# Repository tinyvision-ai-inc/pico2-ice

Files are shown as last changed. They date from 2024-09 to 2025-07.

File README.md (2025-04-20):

# pico2-ice

[Doc](http://pico2-ice.tinyvision.ai/)
| [Hardware](https://github.com/tinyvision-ai-inc/pico2-ice)
| [SDK](https://github.com/tinyvision-ai-inc/pico-ice-sdk)
| [Schematic](https://raw.githubusercontent.com/tinyvision-ai-inc/pico2-ice/docs/Board/Rev1/pico2-ice.pdf)
| [Assembly](https://htmlpreview.github.io/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)
| [Discord](https://discord.gg/t2CzbAYeD2)

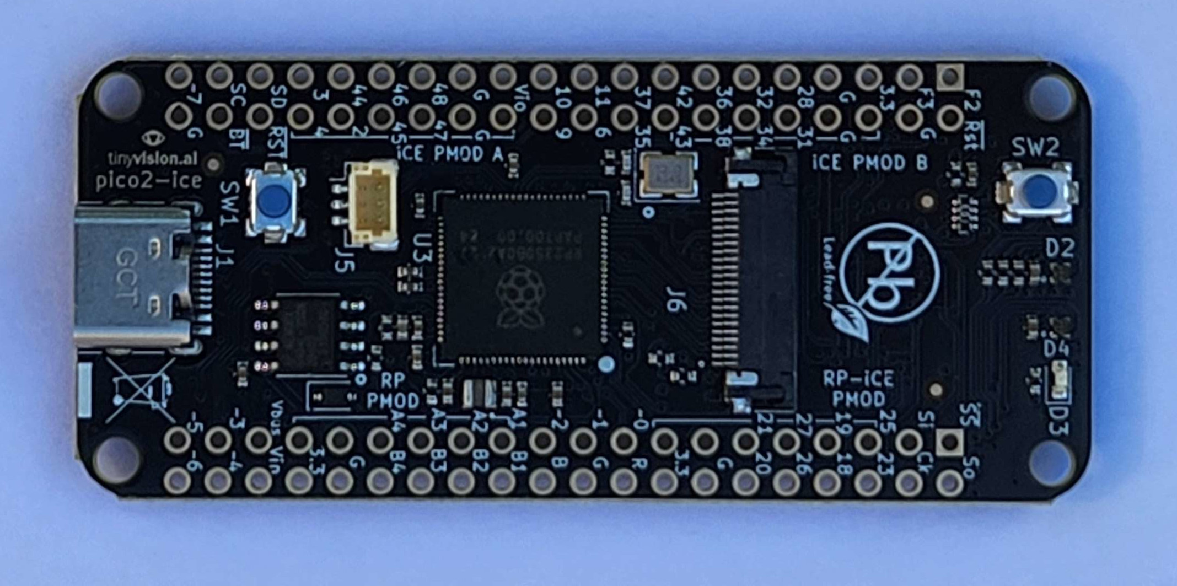
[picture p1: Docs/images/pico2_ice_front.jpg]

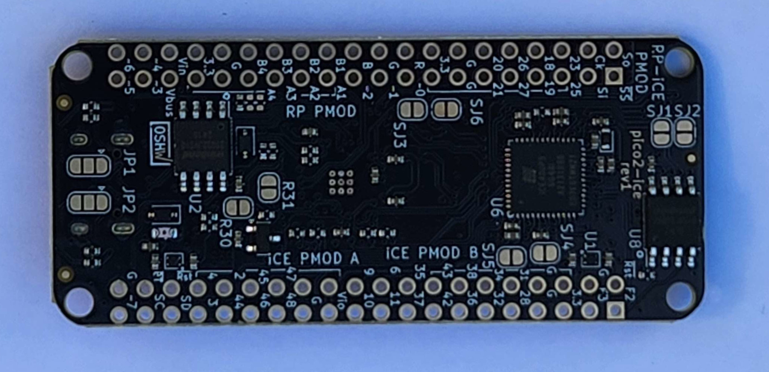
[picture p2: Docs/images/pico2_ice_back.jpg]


## PCB Design Files, Designs, Documentation

The pico2-ice is a small, low cost board with the Raspberry Pi Pico processor ([RP2350](https://www.raspberrypi.com/documentation/microcontrollers/silicon.html#rp2350)) and a Lattice Semiconductor [iCE40UP5K](https://www.latticesemi.com/en/Products/FPGAandCPLD/iCE40UltraPlus) FPGA. The board features independent flash for the FPGA and RP2350, low power PSRAM, a couple of pushbuttons and a two 3 color LED with _all_ FPGA and RP2350 pins brought out to easy to use 0.1" header pins (arranged as Pmod's) for fast prototyping.

The tinyVision.ai pico2-ice board Features:

* Raspberry Pi RP2350B processor
* Lattice UltraPlus ICE40UP5K FPGA with 5.3k LUTs, 1Mb SPRAM, 120Kb DPRAM, 8 Multipliers
* _ALL_ RP2350 and 32 FPGA GPIO on 0.1” headers
* 4MB SPI Flash
* 8MB low power qSPI SRAM
* 2 RGB LED, one for the RP2350 and one for the FPGA
* 2 pushbuttons, 1 for RP2350 boot mode that can also be used for other functions, and one for the FPGA
* On board 3.3V and 1.2V Regulators, can supply 3.3V to your project
* Open source schematic and layout using KiCAD design tools
* 4 layer board with a solid ground plane for good signal integrity

Firmware features:

* FPGA clock supplied by the RP2350, easy to program FPGA clock under SW control
* RP2350 can program the FPGA in various ways
* Micropython Firmware or C SDK

[OSHW US002732](https://certification.oshwa.org/us002732.html) | Certified open source hardware | oshwa.org/cert

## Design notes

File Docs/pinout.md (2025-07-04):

# Pinout Diagram

This diagram shows the ICE40 and RP2350 names for the through holes on the pico2-ice board. 

pinout diagram

[SVG](pinout.svg)
| [RP2350B](https://www.raspberrypi.com/documentation/pico-sdk/hardware.html#autotoc_md0)
| [ICE40](https://www.latticesemi.com/view_document?document_id=51971)

## With RTL on the iCE40

To program the FPGA, one needs to tell the synthesis tools which pins to connect to the signals in your RTL.  There are two different ways to name the pins.   The wafer names are words like `IOB_6a` and `IOT_8b`, and the pin numbers have names like `ICE_2`, `ICE_3`, and `ICE_4`.
Both sets of names can be found in this [PCF file](https://github.com/tinyvision-ai-inc/pico-ice-sdk/blob/main/rtl/pico_ice.pcf).

## With code on the RP2350

The FPGA pins and other signals are defined in [`pico_ice.h`](https://github.com/tinyvision-ai-inc/pico-ice-sdk/blob/pico2-ice_develop/include/boards/pico2_ice.h).

The PMOD pins can also be accessed from
[`ice_pmod.h`](https://github.com/tinyvision-ai-inc/pico-ice-sdk/blob/pico2-ice_develop/include/ice_pmod.h).

## SPI Pinouts 

For debugging the FPGA <-> SPI <-> Flash/RAM interface it is very helpful to use the 4 through holes on the upper right of the FPGA, and to connect a logic analyzer to the upper right PMOD.
Remember that the default boot process leaves the Flash switched ``off``.
With the Yosys icepack command, the ``-s`` option boots the Flash in the ``on`` state.

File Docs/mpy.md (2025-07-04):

# MicroPython

Pico-ice and pico2-ice support [MicroPython](https://micropython.org/).

## To install

- Acquire the [latest release](https://github.com/tinyvision-ai-inc/pico-ice-micropython/releases/latest) for the device you have.
- Program this `.uf2` file into the RP2350 as documented [here](programming_the_mcu.md).

## To use

The API to use the FPGA is as follow:

- `ice` is the microypthon module: `import ice`
- `ice.fpga` is the class provided by the module to manage the ICE40 FPGA: `ice.fpga(...)`
- `ice.fpga` provides the methods `stop()`, `start()`, and `cram(file)`

## How to program a bitstream to the FPGA RAM

- The `Pin` class is imported from the machine module to provide interfacing with the hardware.
- The module is imported
- The fpga type is configured with the approriate pins for the device, as well as the frequency (in MHz) that the FPGA will run at.
- The bitstream file is opened, in byte (as opposed to text) mode (`b`), to read (`r`).
- The fpga is brought out of reset with `fpga.start()`
- The bitstream is loaded into the FPGA using `fpga.cram(file)` with the previously opened file as argument.

### On pico-ice:

Make sure to adjust `frequency=` to the same frequency used by your FPGA design.
Often a lower value such as 12 MHz.

```python
from machine import Pin
import ice
fpga = ice.fpga(cdone=Pin(26), clock=Pin(24), creset=Pin(27), cram_cs=Pin(9), cram_mosi=Pin(8), cram_sck=Pin(10), frequency=48)
file = open("bitstream.bin", "br")
fpga.start()
fpga.cram(file)
```

### On pico2-ice:

Make sure to adjust `frequency=` to the same frequency used by your FPGA design.
Often a lower value such as 12 MHz.

```python
from machine import Pin
import ice
fpga = ice.fpga(cdone=Pin(40), clock=Pin(21), creset=Pin(31), cram_cs=Pin(5), cram_mosi=Pin(4), cram_sck=Pin(6), frequency=48)
file = open("bitstream.bin", "br")
fpga.start()
fpga.cram(file)
```

## How to program a bistream to the FPGA Flash (persistent bitstream)

### On pico-ice:

Make sure to adjust `frequency=` to the same frequency used by your FPGA design.
Often a lower value such as 12 MHz.

```python
from machine import Pin
import ice
file = open("bitstream.bin", "br")
flash = ice.flash(miso=Pin(8), mosi=Pin(11), sck=Pin(10), cs=Pin(9))
flash.erase(4096) # Optional
flash.write(file)
# Optional
fpga = ice.fpga(cdone=Pin(26), clock=Pin(24), creset=Pin(27), cram_cs=Pin(9), cram_mosi=Pin(8), cram_sck=Pin(10), frequency=48)
fpga.start()
```

### On pico2-ice:

Make sure to adjust `frequency=` to the same frequency used by your FPGA design.
Often a lower value such as 12 MHz.

```python
from machine import Pin
import ice
file = open("bitstream.bin", "br")
flash = ice.flash(miso=Pin(4), mosi=Pin(7), sck=Pin(6), cs=Pin(5))
flash.erase(4096) # Optional
flash.write(file)
# Optional
fpga = ice.fpga(cdone=Pin(40), clock=Pin(21), creset=Pin(31), cram_cs=Pin(5), cram_mosi=Pin(4), cram_sck=Pin(6), frequency=48)
fpga.start()
```

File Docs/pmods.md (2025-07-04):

# Using Pmods

The Pmod Connection system is using a grid of 2 rows and 6 columns of pins.

It was designed by Digilent to offer something compatible with both classical jumper wires used on breadboards,
and a standardised pinout that supports multiple protocols on the same connector.

This is popular on FPGA boards as it permits them to support any protocol over
the same connector with the right pinout, rarely possible on MCUs.

This standard is documented [here](https://reference.digilentinc.com/_media/reference/pmod/pmodoledrgb/pmodoledrgb_sch.pdf).

## Pmod in the pico-ice

Here is an [example of how to solder](md_getting__started.html#autotoc_md2) the Pmod connectors.

There are 4 Pmod connectors in the pico-ice.

- `ICE PMOD A` connected to the iCE40 only
- `ICE PMOD B` connected to the iCE40 only
- `RP-ICE PMOD` connected to both the RP2350 and iCE40
- `RP PMOD` connected to the RP2350 only

The pinout of the RP2350 is made to be compatible with SPI,
with the other protocols that may be bit-banged or implemented with PIO to be pin-compatible.

For the iCE40, the pin numbers are available from
[`pico2_ice.pcf`](https://github.com/tinyvision-ai-inc/pico-ice-sdk/blob/main/rtl/pico2_ice.pcf).

## Pmod Modules

There are many Pmod vendors, and this page attempts to enumerate as many as possible.

If you have made a Pmod module, let us know and we would add it to this list!

- <https://www.infineon.com/cms/en/search.html#!term=pmod&view=products>
- <https://digilent.com/shop/boards-and-components/system-board-expansion-modules/pmods/>
- <https://www.renesas.com/us/en/software-tool/quick-connect-iot-platform>
- <https://www.tindie.com/stores/johnnywu/>
- <https://1bitsquared.com/collections/fpga>
- <https://www.tindie.com/search/?q=pmod>
- <https://lectronz.com/products/search?q=pmod>
- <https://www.aries-embedded.com/evaluation-kit/tools/pmod-extension-module>
- <https://github.com/wuxx/icesugar/tree/master/schematic>
- <https://machdyne.com/?s=pmod&post_type=product>
- <https://aliexpress.com/store/912189181/search?SearchText=pmod>
- <https://github.com/swetland/ethernet-pmod>
- <https://fpga.fm4dd.com/>
- <https://github.com/icebreaker-fpga/icebreaker-pmod>
- <https://blackmesalabs.wordpress.com/>
- <https://www.solder.party/docs/keyboard-pmod/pmod-to-qwiic-adapter/>
- <https://github.com/marcinwachowiak/pmod-pdm-microphone-array/>
- <https://github.com/apfelaudio/eurorack-pmod>

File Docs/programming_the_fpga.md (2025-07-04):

# Programming the iCE40

The FPGA normally boots from a dedicated serial NOR flash.
This flash can be programmed by the Pico processor which exposes the flash to the host OS as either a removable drive or a DFU endpoint.

On Windows, while the RaspberryPi guide mentions using Visual Studio Code with a plugin a an IDE, better results were obtained by using the [WSL2 environment](https://learn.microsoft.com/en-us/windows/wsl/install).

## With Micropython

Out of the box, pico2-ice comes with a micropython firmware loaded in the RP2350, you can use it to upload bitstreams to the FPGA:

1. Copy bitstream file to the USB MSC disk provided by micropython, unplug and replug the pico2-ice. Alternatively, use mpremote to copy the file `mpremote cp file.bin :`

2. See the usage of micropython to upload your bitstream to FPGA flash or FPGA RAM: [How to use Micropython](md_mpy.html)

## Troubleshooting

### Checking the CDONE pin

Once the FPGA bitfile transfers over using the DFU protocol,
the Pico will check for whether the DONE pin goes high indicating a successful boot.
This would make the CDONE green LED bright.
If this doesnt happen for whatever reason,
the DFU utility will throw an error indicating that this did not succeed.

### Booting the FPGA with custom firmware

The user writing a custom firmware with the pico-ice-sdk should take care of starting the FPGA from the MCU.
Review the [rp2_fpga](https://github.com/tinyvision-ai-inc/pico-ice-sdk/tree/main/examples/rp2_fpga) example
for how this can be done.

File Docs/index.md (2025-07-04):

[Doc](http://pico2-ice.tinyvision.ai/)
| [Hardware](https://github.com/tinyvision-ai-inc/pico2-ice)
| [SDK](https://github.com/tinyvision-ai-inc/pico-ice-sdk)
| [Schematic](https://raw.githubusercontent.com/tinyvision-ai-inc/pico2-ice/docs/Board/Rev1/pico2-ice.pdf)
| [Assembly](https://htmlpreview.github.io/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)
| [Discord](https://discord.gg/t2CzbAYeD2)




The pico2-ice is a small, low cost board with the Raspberry Pi Pico processor ([RP2350](https://www.raspberrypi.com/documentation/microcontrollers/silicon.html#rp2350)) and a Lattice Semiconductor [iCE40UP5K](https://www.latticesemi.com/en/Products/FPGAandCPLD/iCE40UltraPlus) FPGA. The board features independent flash for the FPGA and RP2350, low power PSRAM, a couple of pushbuttons and a two 3 color LED with _all_ FPGA and RP2350 pins brought out to easy to use 0.1" header pins (arranged as Pmod's) for fast prototyping.




Board Hardware Features:

* Raspberry Pi RP2350B processor
* Lattice UltraPlus ICE40UP5K FPGA with 5.3k LUTs, 1Mb SPRAM, 120Kb DPRAM, 8 Multipliers
* _ALL_ RP2350 and 32 FPGA GPIO on 0.1” headers
* 4MB SPI Flash
* 8MB low power qSPI SRAM
* 2 RGB LED, one for the RP2350 and one for the FPGA
* 2 pushbuttons, 1 for RP2350 boot mode that can also be used for other functions, and one for the FPGA
* On board 3.3V and 1.2V Regulators, can supply 3.3V to your project
* Open source schematic and layout using KiCAD design tools
* 4 layer board with a solid ground plane for good signal integrity

Board Firmware features:

* FPGA clock supplied by the RP2350, easy to program FPGA clock under SW control
* RP2350 can program the FPGA in various ways

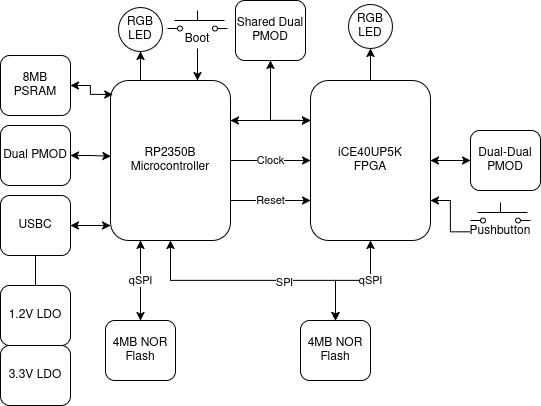
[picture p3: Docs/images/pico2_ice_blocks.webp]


[OSHW US002732](https://certification.oshwa.org/us002732.html) | Certified open source hardware | oshwa.org/cert

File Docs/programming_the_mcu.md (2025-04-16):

# Programming the RP2350

To upload a new firmware image on the RP2350 (the "pico" part of "pico2-ice"), you need to switch to that RP2350 UF2 bootloader mode instead of the FPGA UF2 mode.

You can do that by connecting a jumper between the `BT` pin a `Gnd` pin or hold the SW1 button, then toggle power:

1. Connect the `BT` pin to ground or hold the SW1 button. For instance with a pair of tweezers, a jumper, or an uncoated paper clip.

2. Toggle power to the RP2350, for example by unplugging and re-plugging the USB cable.

3. Disconnect the `BT` pin from ground.

4. Look for an USB drive named `RP2350` and mount it, open it, and check that there are only 2 files in it: `INFO.HTML` and `INFO_UF2.TXT`.

5. Copy the `.uf2` firmware file onto the USB drive.

6. Eject the USB drive.
   At this step, the firmware should be uploaded and running.

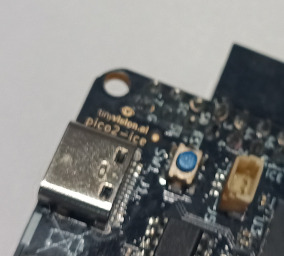
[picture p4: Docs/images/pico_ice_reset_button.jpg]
photo of button near the shortable pins


Since version [`v1.6.1`](https://github.com/tinyvision-ai-inc/pico-ice/releases),
it is possible to reboot the pico2-ice into bootloader "BOOTSEL" mode without jumpers:

    picocom --baud 1200 /dev/ttyACM0

This uses the [convention established by Arduino boards](https://arduino.github.io/arduino-cli/dev/platform-specification/#1200-bps-bootloader-reset)
which reset into bootloader mode when connecting with baud 1200.

After this, it becomes possible to use the [picotool](https://github.com/raspberrypi/picotool) to control the firmware (upload, check version, reboot):

    $ sudo picotool info
    Program Information
     name:      pico_ice_default
     features:  USB stdin / stdout

## Troubleshooting

### RPI-RP2 is still visible after step 6

This means the device remained in "bootloader" mode.
One thing to check is that the `BT` pin is not connected to anything anymore,
then try to reset the board.

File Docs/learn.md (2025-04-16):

# Learning FPGA Design

A large number of resources exists for learning FPGA design.

Some of them have been collected and aggregated on this page.

An online class was held by tinyVision.ai, and is available freely:

- [Hands-on-FPGA-class](https://github.com/tinyvision-ai-inc/Hands-on-FPGA-class/)

## Video format

- [Digi-Key Intro to FPGA](https://www.youtube.com/watch?v=lLg1AgA2Xoo)
  Starts with defining FPGA and covers HDLs, programming flow etc.
  New to FPGAs? Start here!

- [SystemVerilog in 5 minutes](https://www.bilibili.com/video/BV1Rr4y1z7Dv?p=1)
  Serie of concise and focused descriptions of the SystemVerilog language.

- [VLSI Chaps](https://youtube.com/channel/UCzvXC7WbnaWs5FZ5djO8cag)
  Discussion and explanation of ASICs, VLISI, but also SystemVerilog.

- [Digital to FPGA 101](https://youtu.be/FcFbFTbngrw)
  design a circuit in digital convert into verilog and run it on an ice40 FPGA (like Upduino_v3.1).

## Examples

- [icebreaker-verilog-examples](https://github.com/icebreaker-fpga/icebreaker-verilog-examples)
  A collection of examples using Makefiles for iCE40 boards.
  Can be used for the `pico2-ice` with minor adaptations.

- [Xark's upduino-example](https://github.com/XarkLabs/upduino-example/tree/master)
  An example for how to use a Makefile for building a Verilog.
  Can be used for the `pico2-ice` with minor adaptations.

- [tnt's ice40-playground](https://github.com/smunaut/ice40-playground/)
  S. Munaut's examples for the iCE40.

- [Librecores](https://www.librecores.org/)
  Index of open source cores (Verilog, VHDL...) projects. Good Verilog examples.

- [Upduino v2 icestorm examples](https://github.com/osresearch/up5k)
  large collection of very useful code, and a good overview. Upduino v2 only.

## General tutorials

- [Hobbyist's guide to FPGAs](https://hackaday.io/project/27550-the-hobbyists-guide-to-fpgas)
  FPGA tutorials, theory of design articles, hands-on labs targeted towards hobbyists.

- [VHDL Wiz](https://vhdlwhiz.com/)
  Community offering tutoring focused on VHDL.

- [Hardware as Code](https://www.hackster.io/sthibault/hardware-as-code-part-i-an-introduction-48bacb)
  A 5-part tutorial series using the UPduino as an example.

- [fpga 101 fpgas for beginners](https://www.nandland.com/articles/fpga-101-fpgas-for-beginners.html)
  Tutorial explaining concepts and practice with videos and articles.

- [Alchitry](https://alchitry.com/)
  Tutorial focused on the Artix 7 Alchitry boards.

- [Fomu Workshop](https://workshop.fomu.im/en/latest/)
  Workshop by FOMU the ICE40 FPGA that fits on an USB port.

- [Open FPGA Verilog Tutorial](https://github.com/Obijuan/open-fpga-verilog-tutorial/wiki)
  Excellent tutorial series for beginners and the more experienced.

- [Atadiat](https://atadiat.com/en/)
  Introduction about FPGA in both English and Arabic languages.

- [Verilog Tutorial for beginners](http://www.referencedesigner.com/tutorials/verilog/verilog_01.php)
  Verilog Tutorial Series.

- [CircuitVerse](https://learn.circuitverse.org/)
  Teaching verilog through an interactive book with challenges along the way.

- [ASIC-World Tutorial on Verilog](https://www.asic-world.com/verilog/veritut.html)
  Introduction to Verilog oriented toward ASICs and chip design.

- [FPGA-4-fun](https://www.fpga4fun.com/)
  Tutorials covering many practical problems with FPGAs.
  Lots of info and very well put together

- [Lattice IceCube2 Tutorial](https://hsel.co.uk/2018/05/21/lattice-ice40-ultra-plus-fpga-gnarly-grey-upduino-tutorial-1-the-basics/)
  A tutorial on Lattice's IceCube2 software/ide.
  IceCube2 is no longer recommended, replaced by Radiant

- [VLSI Chaps](https://youtube.com/channel/UCzvXC7WbnaWs5FZ5djO8cag)
  Discussion and explanation of ASICs, VLISI, but also SystemVerilog.

- [Digital to FPGA 101](https://youtu.be/FcFbFTbngrw)
  design a circuit in digital convert into verilog and run it on an ice40 FPGA (like Upduino_v3.1).

- [Verilog Tutorial](http://www.asic-world.com/verilog/veritut.html)
  Tutorial series on verilog with example code.
  all examples are synthesizable in icarus verilog simulator

- [CFU Playground](https://cfu-playground.readthedocs.io/en/latest/)
  The "Crash Course on Everything" is a good introduction

- [VHDL in an hour](https://www.jopdesign.com/teaching/VHDL.pdf)
  Fast paced but practical guide to VHDL.
  longest hour ever

- [First look at Prog. Logic](https://www.allaboutcircuits.com/technical-articles/a-microcontroller-enthusiast-first-look-at-programmable-logic/)
  Getting started w/FPGAs article series 1.

- [Sparkfun So you want to learn FPGAs](https://www.sparkfun.com/news/1203)
  Sparkfun article introducing to FPGAs.

- [ZIPCPU](http://zipcpu.com/)
  Articles by Gisselquist explaining design,verification, and more.

- [FPGA Workshop](https://github.com/ranzbak/fpga-workshop)
  Basic FPGA development for absolute beginners featuring the Upduino V2.

- [Upduino FPGA Tutorial](https://blog.idorobots.org/entries/upduino-fpga-tutorial.html)
  UPduino FPGA tutorial using APIO.

- [Installing the Icestorm Toolchain](https://www.youtube.com/watch?v=Bfhnu9XUzLs)
  Guide on getting comfortable with a Makefile-based development process for Icestorm/Yosys and Verilog.

- [Explanation of essential Verilog concepts](https://vanhunteradams.com/DE1/Lorenz/Verilog.html)
  Several pitfalls and myths debunked about the Verilog language, as part of an introduction.

## Specific topic

- [clock domain crossing](http://fpgacpu.ca/fpga/handshake.html)
  Sending data across modules of two different clock domain: clock domain crossing.

- [lowRISC Verilog Coding Style](https://github.com/lowRISC/style-guides/blob/master/VerilogCodingStyle.md)
  Set of rules for formatting and organizing Verilog code.
  Not difficult per-se, but problem encountered after initial discovery of Verilog is over

- [Interfacing FPGAs to an ADC’s Digital Data Output](https://www.analog.com/en/technical-articles/interfacing-fpgas-to-an-adcs-digital-data-output.html)
  Article from Analog Design exploring the topic of ADC/DAC <-> FPGA interface.

- [RISC-V on an ICE40 FPGA](https://pingu98.wordpress.com/2019/04/08/)
  A very detailed blog on implementing a RISC-V in the FPGA.

- [RISC-V on an iCE40 FPGA](https://github.com/BrunoLevy/learn-fpga)
  by the author of the relatively high-performance yet tiny RISC-V core FemtoRV.

## Wiki

- [VHDL Wiz Terminology](https://vhdlwhiz.com/terminology/)
  Glossary of many concepts.

- [VHDL Wiz Terminology](https://vhdlwhiz.com/terminology/)
  Glossary of many concepts.

- [Hamsterworks wiki](https://web.archive.org/web/20190115080828/http://hamsterworks.co.nz/mediawiki/index.php/Main_Page)
  Introduction to FPGAs focused on VHDL.
  The site is offline, but an archive of the content is still available.

- [VerilogGuide](https://verilogguide.readthedocs.io/)
  Wiki/Book for learning Verilog from the ground up.
  Uses Quartus and ModelSim-Altera Starter instead of the open source toolchain

- [Chipress](https://chipress.online/)
  Collection of explanations targetted at aspiring ASICs engineers.
  Many of the topics are related

- [ChipVerify](https://www.chipverify.com/)
  Wiki covering much of Verilog and SystemVerilog syntax.

- [FPGA key](https://www.fpgakey.com/)
  Community focused on providing resources to learn FPGAs.

## Simulators

- [EDA playground](https://www.edaplayground.com/home)
  Online IDE and simulator, quickest way to get started without a dev board.

- [Verilator](https://www.veripool.org/verilator/)
  Simulator for Verilog code.
  Convert the simulation to a C++ code library that exposes signals as C variables.

- [Icarus Verilog](http://iverilog.icarus.com/)
  Simulator for Verilog code.

- [Digital](https://github.com/hneemann/Digital/releases)
  digital logic circuit simulator based on logisim.
  Alternative: https://github.com/logisim-evolution/logisim-evolution

- [HDL Bits](https://hdlbits.01xz.net/wiki/Main_Page)
  Interactive (in browser) verilog syntax lessons.
  initially assumes no prior knowledge of HDLs but quickly ramps up difficulty

## Toolchains

- [oss-tabby-cad](https://github.com/YosysHQ/oss-cad-suite-build)
  A complete toolchain based on top of Yosys.

- [Yosys](https://yosyshq.net/yosys/)
  The central tool connecting the languages front-end and back-ends.

- [GHDL](https://ghdl.github.io/ghdl/)
  Simulator for VHDL code.

- [MixedSim](https://www.isotel.eu/mixedsim/)
  Tool building on top of ngspice for simulating circuits.

- [verilog to routing](https://verilogtorouting.org/)
  Open-Source toolchain alternative to YoSys.

- [open FPGA](https://github.com/azonenberg/openfpga)
  Older toolchain for CPLD.

- [FASM](https://fasm.readthedocs.io/en/latest/)
  Low-level format aiming to be a de-facto industry standard for FPGA toolchains.

## Courses

- [Hands-on FPGA class](https://github.com/tinyvision-ai-inc/Hands-on-FPGA-class/)
  A 8-week class was given by tinyVision.ai for getting started with FPGAs.

- [Intel FPGA Academy](https://fpgacademy.org/courses.html)
  Digital logic/FPGA courses by Intel.
  requires .edu email (contact intel for access without .edu email but response may vary)

- [fpga4fun FPGAs 1 - What are they?](https://www.fpga4fun.com/FPGAinfo1.html)
  Intro to FPGA lesson 1.
  Link is forr lesson 1 of intro to FPGA but the entire site is dedicated to learning FPGAs

- [WTFpga Workshop](https://github.com/icebreaker-fpga/wtfpga)
  Guided discovery of FPGA through the IceBreaker board.

- [IceBreaker Workshop](https://github.com/icebreaker-fpga/icebreaker-workshop)
  Course focused on getting started through the IceBreaker board.

- [Intro to Digital Logic Circuits](http://www.ece.tufts.edu/es/4/)
  University course by Steven Bell that assumes little/no prior knowledge of FPGAs.
  Features the Upduino v3 and "Digital Design and Computer Architecture arm edition"

- [Digital System Design (DSD) Spring 2009](http://www.ee.ic.ac.uk/pcheung/teaching/ee3_DSD/)
  Course introducing FPGAs to students.

- [MIT 6.205 Course](https://fpga.mit.edu/6205/F22)
  Requires log-in to access the whole content, but good introductory text.

- [ECE 5760 Course](https://people.ece.cornell.edu/land/courses/ece5760/)
  A class that widely publishes their teaching material, allowing 3rd-party
  students to attempt it on their own.

## Other lists

- [F4PGA Link list](https://github.com/f4pga/ideas/issues/52)
  Another project aiming to collect links.

- [FPGA Design Elements](http://fpgacpu.ca/fpga/index.html)
  coding style and notes about various building blocks/design principles.
  Fantastic list of resources/code examples etc

- [HDL Simulators](https://en.wikipedia.org/wiki/List_of_HDL_simulators)
  Wikipedia list of simulators for HDLs.

- [sv-tests results](https://chipsalliance.github.io/sv-tests-results/)
  Table summarizing support for all SystemVerilog (and Verilog) features support in various tool..
  Useful to check compatibility of a toolchain

## Books

- [PLD World E-books](http://ebook.pldworld.com/_eBook/FPGA%EF%BC%8FHDL/-Eng-/)
  ebooks about all things HDL/FPGA/PLD etc.

- [Digital systems design using VHDL](https://www.pdfdrive.com/digital-systems-design-using-vhdl-d166870425.html)
  VHDL/digital design textbook by Charles H. Roth Jr & Lizy K. John.

- [FPGAs now what?](https://xess.com/static/media/appnotes/FpgasNowWhatBook.pdf)
  FPGA e-book that employs a hands on/learn by doing approach.

- [SystemVerilog RTL Modeling, Simulation, Verification](https://systemverilog.dev/)
  Online book on SystemVerilog using Cadence tools or EDA Playground.
  Work in progress

- [Digital Logic Pocket Data Book](https://www.ti.com/lit/ug/scyd013b/scyd013b.pdf)
  pinout/reference for TI Logic ICs (74xx series etc).
  Not exactly FPGA related, but useful for configuring the FPGA like common logic ICs

## Organizations

- [Build an FPGA from 7400 series ICs](http://blog.notdot.net/2012/10/Build-your-own-FPGA)
  DIY FPGA competition submission and source.
  https://github.com/arachnid/dfpga

- [Libre-SOC](https://libre-soc.org/)
  Open source high performance CPU/GPU/VPU on a chip.
  Focused on high performance open-sourced OpenPOWER architecture

- [F4PGA](https://f4pga.org/)
  Umbrella project based on Yosys for synthesis of code toward an HDL..
  Good place to first learn about toolchains, but some dead links

## Research papers

- [Sunburst design whitepapers](http://www.sunburst-design.com/papers/)
  reference papers on coding standard etc..
  Range of difficulties

## Games

- [NandGame](https://nandgame.com/)
  Browser based puzzle game about logic gates.
  serves as litmus test to determine familiarity with digital logic. Good for visual learners

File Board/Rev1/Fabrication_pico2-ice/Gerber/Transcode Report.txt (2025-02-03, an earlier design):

   ---- Transcoding 'E:\Works\BibinCJoseph\PCIO2-ice\Rev1\Rev1\Fabrication\Gerber\pico2-ice-B_Fab.gbr' ----   Sun Feb  2 23:54:44 2025

D15   --> D100
D16   --> D101
D17   --> D102
D18   --> D103
D19   --> D104
-----------------------------------------------------------------

   ---- Transcoding 'E:\Works\BibinCJoseph\PCIO2-ice\Rev1\Rev1\Fabrication\Gerber\pico2-ice-B_Paste.gbr' ----   Sun Feb  2 23:54:44 2025

D14   --> D105
D15   --> D106
D16   --> D107
D17   --> D108
D18   --> D109
D19   --> D110
D20   --> D111
D21   --> D112
D22   --> D113
D23   --> D114
D24   --> D115
D25   --> D116
D26   --> D117
D27   --> D118
D28   --> D119
D29   --> D120
D30   --> D121
D31   --> D122
D32   --> D123
D33   --> D124
D34   --> D125
D35   --> D126
D36   --> D127
D37   --> D128
D38   --> D129
-----------------------------------------------------------------

   ---- Transcoding 'E:\Works\BibinCJoseph\PCIO2-ice\Rev1\Rev1\Fabrication\Gerber\pico2-ice-B_Silkscreen.gbr' ----   Sun Feb  2 23:54:44 2025

D14   --> D130
D15   --> D131
D16   --> D132
D17   --> D133
D18   --> D134
-----------------------------------------------------------------

   ---- Transcoding 'E:\Works\BibinCJoseph\PCIO2-ice\Rev1\Rev1\Fabrication\Gerber\pico2-ice-drl_map.gbr' ----   Sun Feb  2 23:54:44 2025

D10   --> D135
D11   --> D136
D12   --> D137
D13   --> D138
-----------------------------------------------------------------

   ---- Transcoding 'E:\Works\BibinCJoseph\PCIO2-ice\Rev1\Rev1\Fabrication\Gerber\pico2-ice-F_Cu.gbr' ----   Sun Feb  2 23:54:44 2025

D14   --> D139
D15   --> D140
D16   --> D141
D17   --> D142
D18   --> D143
D19   --> D144
D20   --> D145
D21   --> D146
D22   --> D147
D23   --> D148
D24   --> D149
D25   --> D150
D26   --> D151
D27   --> D152
D28   --> D153
D29   --> D154
D30   --> D155
D31   --> D156
D32   --> D157
D34   --> D158
D35   --> D159
D36   --> D160
D37   --> D161
D38   --> D162
D39   --> D163
D40   --> D164
D41   --> D165
D42   --> D166
D43   --> D167
D44   --> D168
D45   --> D169
D46   --> D170
D47   --> D171
D48   --> D172
D49   --> D173
D50   --> D174
D51   --> D175
D52   --> D176
D53   --> D177
D54   --> D178
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
-----------------------------------------------------------------

   ---- Transcoding 'E:\Works\BibinCJoseph\PCIO2-ice\Rev1\Rev1\Fabrication\Gerber\pico2-ice-F_Fab.gbr' ----   Sun Feb  2 23:54:44 2025

D15   --> D180
D16   --> D181
D17   --> D182
D18   --> D183
D19   --> D184
D20   --> D185
D21   --> D186
D22   --> D187
D23   --> D188
-----------------------------------------------------------------

   ---- Transcoding 'E:\Works\BibinCJoseph\PCIO2-ice\Rev1\Rev1\Fabrication\Gerber\pico2-ice-F_Paste.gbr' ----   Sun Feb  2 23:54:44 2025

D14   --> D189
D15   --> D190
D16   --> D191
D17   --> D192
D18   --> D193
D19   --> D194
D20   --> D195
D21   --> D196
D22   --> D197
D23   --> D198
D24   --> D199
D25   --> D200
D26   --> D201
D27   --> D202
D28   --> D203
D29   --> D204
D30   --> D205
D31   --> D206
D32   --> D207
D33   --> D208
D34   --> D209
D35   --> D210
D36   --> D211
D37   --> D212
D38   --> D213
D39   --> D214
D40   --> D215
D41   --> D216
D42   --> D217
-----------------------------------------------------------------

   ---- Transcoding 'E:\Works\BibinCJoseph\PCIO2-ice\Rev1\Rev1\Fabrication\Gerber\pico2-ice-F_Silkscreen.gbr' ----   Sun Feb  2 23:54:44 2025

D14   --> D218
D15   --> D219
D16   --> D220
D17   --> D221
D19   --> D222
D20   --> D223
D21   --> D224
-----------------------------------------------------------------

   ---- Transcoding 'E:\Works\BibinCJoseph\PCIO2-ice\Rev1\Rev1\Fabrication\Gerber\pico2-ice-In1_Cu.gbr' ----   Sun Feb  2 23:54:44 2025

D14   --> D225
D15   --> D226
D16   --> D227
D17   --> D228
D18   --> D229
D19   --> D230
D20   --> D231
D21   --> D232
D22   --> D233
-----------------------------------------------------------------

   ---- Transcoding 'E:\Works\BibinCJoseph\PCIO2-ice\Rev1\Rev1\Fabrication\Gerber\pico2-ice-In2_Cu.gbr' ----   Sun Feb  2 23:54:44 2025

D14   --> D234
D15   --> D235
D16   --> D236
D17   --> D237
D18   --> D238
D19   --> D239
D20   --> D240
D21   --> D241
D22   --> D242
D23   --> D243
-----------------------------------------------------------------

   ---- Transcoding 'E:\Works\BibinCJoseph\PCIO2-ice\Rev1\Rev1\Fabrication\Gerber\pico2-ice-User_Drawings.gbr' ----   Sun Feb  2 23:54:44 2025

D14   --> D244
D15   --> D245
D16   --> D246
-----------------------------------------------------------------

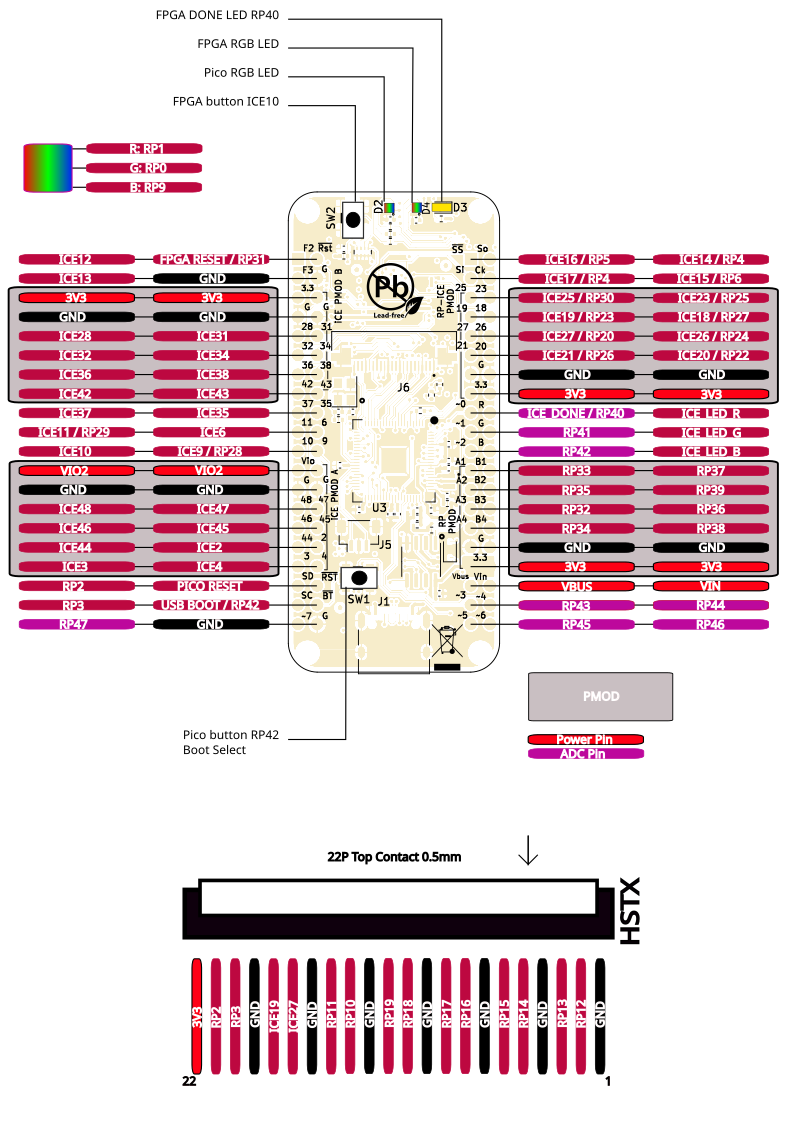
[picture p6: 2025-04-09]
Docs/images/pins.png

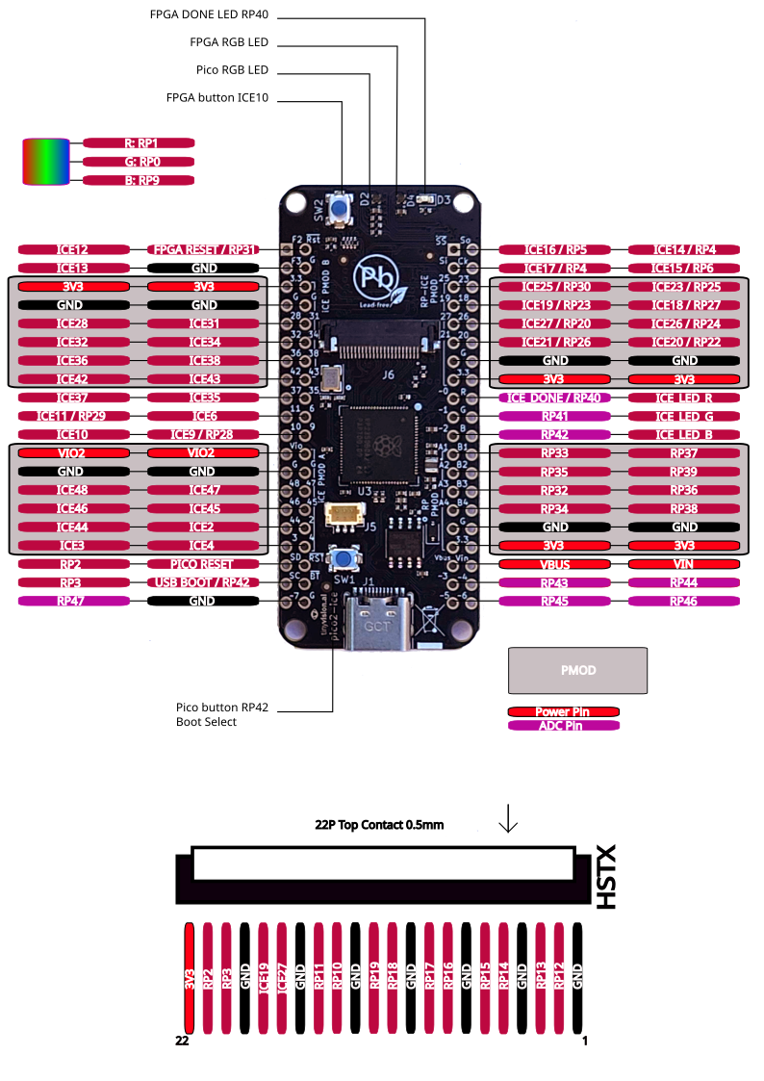
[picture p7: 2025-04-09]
Docs/images/pins2.png

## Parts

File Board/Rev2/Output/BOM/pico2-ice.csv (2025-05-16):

Reference | Value | Description | Qty | Footprint | MPN | Manufacturer | DNP
C1,C2 | 15p | CAP CER 15PF 25V COG 0402 | 2 | Capacitor_SMD:C_0402_1005Metric | GRM1555C1E150JA01D | Murata Electronics
C3,C6,C7,C11,C13,C20,C22,C23,C25,C30,C31,C32,C34,C35,C37,C38,C39,C41 | 4.7u | CAP CER 4.7UF 6.3V X5R 0402 | 18 | Capacitor_SMD:C_0402_1005Metric | GRM155R60J475ME87D | Murata Electronics
C4,C5,C8,C9,C10,C12,C14,C15,C16,C17,C18,C19,C21,C24,C26,C27,C28,C29,C33,C36,C40,C42 | 0.1u | CAP CER 0.1UF 16V X7R 0402 | 22 | Capacitor_SMD:C_0402_1005Metric | GRM155R71C104KA88J | Murata Electronics
D1 | 1N4148WT-7 | DIODE GEN PURP 80V 125MA SOD523 | 1 | Diode_SMD:D_SOD-523 | 1N4148WT-7 | Micro Commercial Co
D2,D4 | MHPA1010RGBDT | Common anode RGB 120° SMD,1x1x0.6mm LED | 2 | CUSTOM:LED_Cree-PLCC4_1x1mm_CW | MHPA1010RGBDT | MEIHUA
D3 | LTST-C191KGKT | LED GREEN CLEAR SMD | 1 | LED_SMD:LED_0603_1608Metric | LTST-C191KGKT | Lite-On
D5,D6,D7 | 1N5819WS | 40V 600mV@1A 1A SOD-323 Schottky Barrier Diodes (SBD) ROHS | 3 | Diode_SMD:D_SOD-323 | 1N5819WS | Guangdong Hottech
FID1,FID2,FID3,FID4,FID5,FID6 | Fiducial |  | 6 | Fiducial:Fiducial_0.75mm_Mask1.5mm | DNP |  | DNP
H1,H2,H3,H4 | MountingHole |  | 4 | MountingHole:MountingHole_2.7mm_M2.5 | DNP |  | DNP
J1 | USB_C_Receptacle_USB2.0 | CONN RCP USB2.0 TYP C 24P SMD RA | 1 | Connector_USB:USB_C_Receptacle_HRO_TYPE-C-31-M-12 | USB4105-GF-A | GCT
J2,J3 | Conn_02x20_Odd_Even |  | 2 | RP2040_minimal:PinHeader_2x20_P2.54mm_Vertical_Left,RP2040_minimal:PinHeader_2x20_P2.54mm_Vertical_Right | DNP |  | DNP
J5 | BM03B-SRSS-TB | CONN HEADER SMD 3POS 1MM | 1 | Connector_JST:JST_SH_BM03B-SRSS-TB_1x03-1MP_P1.00mm_Vertical | BM03B-SRSS-TB | JST Sales America Inc.
J6 | SFV22R-2STE1HLF | Generic connectable mounting pin connector, single row, 01x22, script generated (kicad-library-utils/schlib/autogen/connector/) | 1 | RP2350_60QFN_minimal:AMPHENOL_SFV22R-2STE1HLF | SFV22R-2STE1HLF | AMPHENOL
L1 | 3.3u | FIXED IND 3.3UH 1.2A 150MOHM SMD | 1 | RP2350_60QFN_minimal:L_pol_2016 | MLP2016H3R3MT0S1 | TDK Corporation
PTC1 | MF-FSMF035X-2 | PTC RESET FUSE 6V 350MA 0603 | 1 | Resistor_SMD:R_0603_1608Metric | MF-FSMF035X-2 | Bourns Inc.
R1,R2,R17,R18,R19 | 1k | RES 1K OHM 1% 1/16W 0402 | 5 | Resistor_SMD:R_0402_1005Metric | RC0402FR-071KL | YAGEO
R4,R5,R6,R9,R26,R34 | 27 | RES 27 OHM 1% 1/16W 0402 | 6 | Resistor_SMD:R_0402_1005Metric | RC0402FR-0727RL | YAGEO
R7,R8,R13,R15,R16,R21,R23,R28,R32 | 10K | RES 10K OHM 1% 1/16W 0402 | 9 | Resistor_SMD:R_0402_1005Metric | RC0402FR-0710KL | YAGEO
R10,R24,R33 | 5.1K | RES 5.1K OHM 1% 1/16W 0402 | 3 | Resistor_SMD:R_0402_1005Metric | RC0402FR-075K1L | YAGEO
R11,R25 | 100 | RES 100 OHM 1% 1/16W 0402 | 2 | Resistor_SMD:R_0402_1005Metric | RC0402FR-07100RL | YAGEO
R12 | 1K | RES 1K OHM 1% 1/16W 0402 | 1 | Resistor_SMD:R_0402_1005Metric | RC0402FR-071KL | YAGEO
R14,R29 | 2.2K | RES 2.2K OHM 1% 1/16W 0402 | 2 | Resistor_SMD:R_0402_1005Metric | RC0402FR-072K2L | YAGEO
R20,R22 | 56K | RES 56K OHM 1% 1/16W 0402 | 2 | Resistor_SMD:R_0402_1005Metric | RC0402FR-0756KL | YAGEO
R27 | DNF | DNF | 1 | Resistor_SMD:R_0402_1005Metric |  |  | DNP
R30,R31 | SHORT |  | 2 | Jumper:SolderJumper-2_P1.3mm_Bridged_RoundedPad1.0x1.5mm | DNP
RN1 | 10K | RESARRAY 10K OHM 1% 1/16W 0804 | 1 | Resistor_SMD:R_Array_Concave_4x0402 | YC124-FR-0710KL | YAGEO
SJ1,SJ2,SJ3,SJ4,SJ5,SJ6 | SHORT |  | 6 | Jumper:SolderJumper-2_P1.3mm_Bridged_RoundedPad1.0x1.5mm | DNP
SW1,SW2 | CS1213AGF260 | SWITCH TACTILE SPST-NO 0.05A 50V | 2 | CUSTOM:PTS820J25KSMTRLFS | CS1213AGF260 | CIT Relay and Switch
U1 | NCP115AMX120TCG | IC REG LINEAR 1.2V 300MA 4XDFN | 1 | RP2040_minimal:OnSemi_XDFN4-1EP_1.0x1.0mm_EP0.52x0.52mm | NCP115AMX120TCG | onsemi
U2,U8 | W25Q32JVSSIQ | IC FLASH 32MBIT SPI/QUAD 8SOIC | 2 | Package_SO:SOIC-8_5.23x5.23mm_P1.27mm | W25Q32JVSSIQ | Winbond Elec
U3 | RP2350_80QFN | QFN-80-EP(10x10) Microcontrollers (MCU/MPU/SOC) ROHS | 1 | RP2350_60QFN_minimal:RP2350B_QFN-80_EP_10.573x10.573_Pitch0.4mm | RP2350B | Raspberry Pi
U4 | TL431DBZ | Shunt Regulator, SOT-23 | 1 | Package_TO_SOT_SMD:SOT-23 | TL431BQDBZR | Texas Instruments
U5 | APS6404L-3SQN-SN | DRAM IoT RAM 64Mb SOP8 | 1 | Package_SO:SOIC-8_3.9x4.9mm_P1.27mm | APS6404L-3SQN-SN | AP Memory
U6 | ICE40UP5K-SG48ITR | IC FPGA 39 I/O 48QFN | 1 | Package_DFN_QFN:QFN-48-1EP_7x7mm_P0.5mm_EP5.6x5.6mm | ICE40UP5K-SG48I | Lattice
U9 | NCP115AMX330TCG | IC REG LINEAR 3.3V 300MA 4XDFN | 1 | RP2040_minimal:OnSemi_XDFN4-1EP_1.0x1.0mm_EP0.52x0.52mm | NCP115AMX330TCG | onsemi
Y1 | ABM8-272-T3 | Crystal | 1 | Crystal:Crystal_SMD_3225-4Pin_3.2x2.5mm | ABM8-272-T3 | Abracon

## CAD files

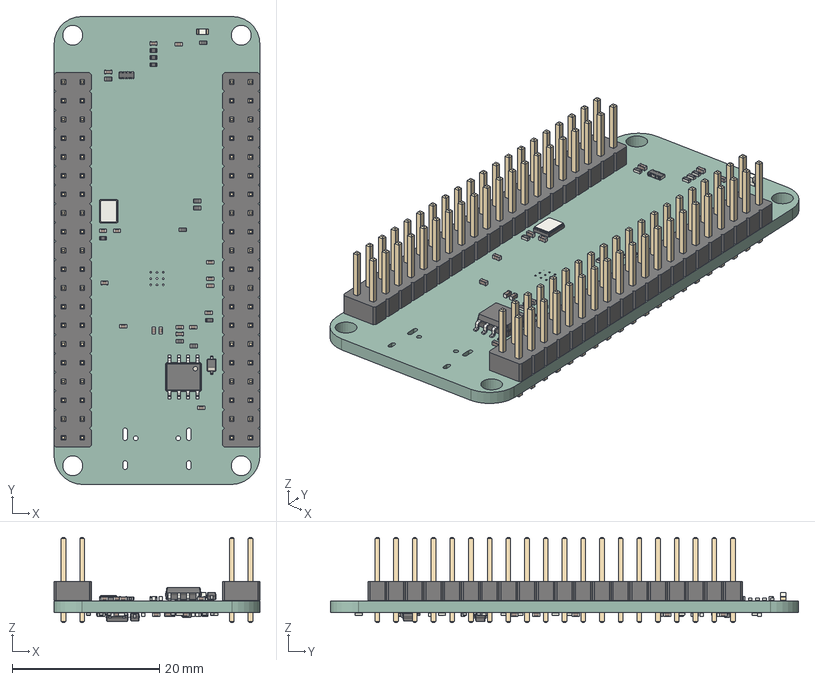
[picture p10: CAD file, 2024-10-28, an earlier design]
Board/Rev0/pico-ice.step
27.9 x 63.5 x 11.5 mm
R_0402_1005Metric x 32
C_0402_1005Metric x 41
LED_0603_1608Metric
D_SOD_323 x 2
SOIC_8_39x49mm_P127mm
PinHeader_2x20_P254mm_Vertical x 2
R_Array_Concave_4x0402
Crystal_SMD_3225-4Pin_3.2x2.5mm
R_0603_1608Metric
SOT_23
D_SOD_523
pico2-ice_PCB

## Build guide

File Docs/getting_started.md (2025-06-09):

# Getting Started

Once you receive the board, you would be able to plug via USB and see the RGB LED blinking.
You might want to update the default firmware to make sure to have the latest bugfixes:

## Default Firmware

[source](https://github.com/tinyvision-ai-inc/pico-ice-micropython) -
[download](https://github.com/tinyvision-ai-inc/pico-ice-micropython/releases)

To provide the various USB programming methods and allow to boot the FPGA, a
default firmware is loaded onto the RP2350 (Pico part of the pico2-ice).

It provides:

- Micropython 1.24.1 or later accessible via USB CDC

- USB MSC to copy data to the Micropython filesystem

- A custom module to flash the FPGA flash or RAM

See [Programming the RP2350](md_programming__the__mcu.html) for how to load this firmware file.

## Soldering the Pmods

In case you ordered the board without the [Pmod](md_pmods.html) connectors soldered,
you would need to solder them in to plug something onto the board.
For instance like this:

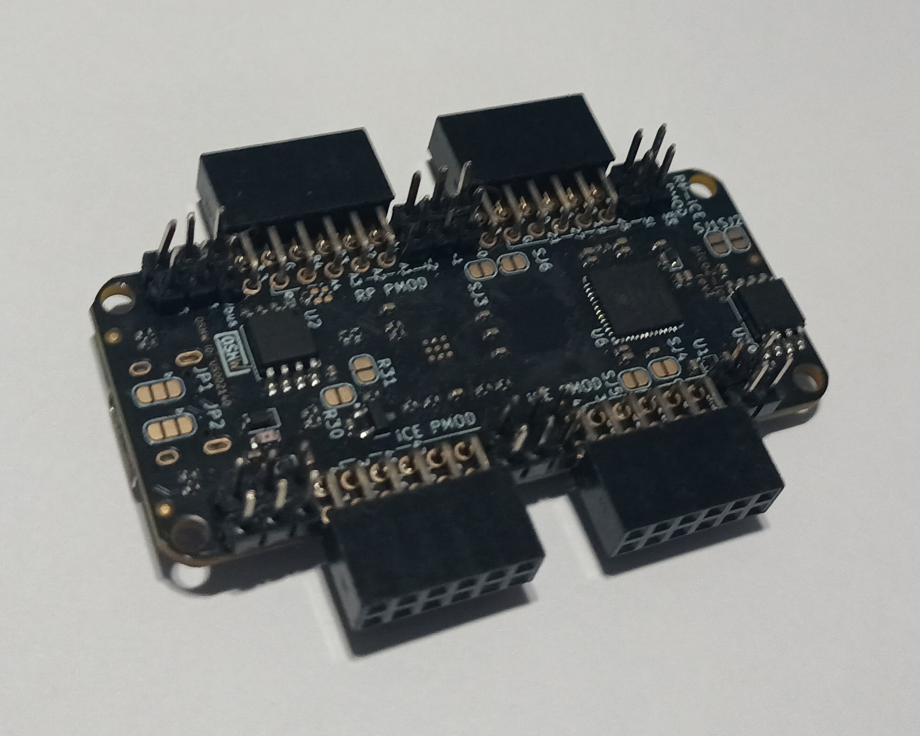
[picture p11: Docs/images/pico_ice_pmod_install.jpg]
pmod install after soldering


## Inserting the Flex into the FPC connector

The high speed port from the RP2350 is connected to J6 which is quite a delicate connector. The FPC conenctor uses a Top Contact, Plunger style connector.

Please see [this guide](https://www.mouser.com/pdfdocs/ENG_DS_1-1773959-6-flexible-printed-circuit-con_1018.pdf) for details on how to connect to it safely without breaking the connector.

## Using the SDK

The [RP2350](https://www.raspberrypi.com/products/rp2350/) on the
pico2-ice can be programmed with either custom C firmware, or languages such as
[MicroPython](https://micropython.org/download/RPI_PICO2/),
[CircuitPython](https://circuitpython.org/board/raspberry_pi_pico2/),
[Go](https://tinygo.org/docs/reference/microcontrollers/pico2/),
[Rust](https://docs.rs/rp2-hal/latest/rp2_hal/),
[JavaScript](https://kalumajs.org/),
[ZeptoForth](https://github.com/tabemann/zeptoforth),
...

Currently C/C++ programming is best suported through the pico-ice-sdk, which is shared between pico-ice and pico2-ice:
a Raspberry Pi [pico-sdk](https://github.com/raspberrypi/pico-sdk/) library.

This is a guide for how to build application running on the RP2350 microcontroller.

The [pico-ice-sdk](https://github.com/tinyvision-ai-inc/pico-ice-sdk/tree/pico2-ice_develop) provides an API for communicating with the pico-ice hardware, also allowing to use the Raspberry Pi [pico-sdk](https://github.com/raspberrypi/pico-sdk/) directly.

The pico-ice-sdk is organised as a normal pico-sdk project with `pico2_ice` custom board.

The [examples](https://github.com/tinyvision-ai-inc/pico-ice-sdk/tree/pico2-ice_develop/examples) show how everything can be to get started.

Here is how to turn an example into a new project:

    # copy the whole example directory
    cp -r pico-ice-sdk/examples/pico_usb_uart my-new-pico-ice-firmware
    cd my-new-pico-ice-firmware

    # turn it into a git repository
    git init
    git remote add origin git@github.com:your-username/my-new-pico-ice-firmware

    # replace the two symlinks by git submodules
    rm pico-sdk pico-ice-sdk
    git submodule add https://github.com/raspberrypi/pico-sdk
    git submodule add https://github.com/tinyvision-ai-inc/pico-ice-sdk

    # fetch the submodules (using --recursive is very slow)
    git -C pico-ice-sdk submodule update --init
    git -C pico-sdk submodule update --init lib/tinyusb

    # you can now build it as a CMake project
    mkdir build && cd build
    cmake -DPICO_BOARD=pico2_ice .. && make

You can now edit the name of the project in the CMakeLists.txt, add new sources, and change the code.

## Troubleshooting

Feel free to join the [chat server](https://discord.gg/sb2kwc66) to ask for help.

### Error: C++ compiler not installed on this system

The pico-sdk is written in C, but uses a single C++ file to enable C++ support in the SDK.
This means you need a working C++ cross compiler, often named `arm-none-eabi-g++`.

Even if this binary is present in your system, it might not be a full C++ installation.
If you do not need C++ and want to work around this bug, you can disable the C++ support
in the pico-sdk. From your project repo:

    $ cd build
    $ cmake .. # download the SDK if not yet done
    $ sed -i '/new_delete.cpp/ d' _deps/pico-sdk-src/src/rp2_common/pico_standard_link/CMakeLists.txt
    $ cmake .. # rebuild the Makefile with the fix

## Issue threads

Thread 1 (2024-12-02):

PMOD related silkscreen has a mistake

vr2045, 2024-12-02:
The lines demarcating the PMOD on the silkscreen for the edge connectors is offset by 1 pin.

vr2045, 2025-01-26:
Fixed

Closed 2025-01-26.

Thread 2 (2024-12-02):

SWD connector is vertical, can this cause issues in mailing?

vr2045, 2024-12-02:
The vertical connector for SWD was added to reduce congestion: should this be horizontal to minimize the possibility of breakage during shipment?

timoksn, 2024-12-03:
if it's placed horizontally, would it be placed on the opposite side of the USB connector (by SW2) ?

vr2045, 2025-01-26:
SWD connector was originally flat but due to board congestion, we had to make it vertical.
Options:
1. Keep it vertical. If we do see this connector getting ripped off during mailing, we can consider changing it or changing the packaging so its more robust?
2. Change to horizontal: lack of board space.

For now, we will try to make this change in the next rev of the board, lets see...

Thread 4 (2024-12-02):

Suggestion: Add silkscreen PMOD id number

timoksn, 2024-12-02:
Add silkscreen PMOD id number if there's enough space
This could help with documentation and tutorials

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

vr2045, 2025-01-26:
The issue shows up with the 2 PMOD's on the left side of the board.
I have called the lower left PMOD as "iCE PMOD A" and the one on the top right "iCE PMOD B". The ones on the right side are already called "RP PMOD" and "RP-iCE PMOD" which should be sufficient.

vr2045, 2025-01-27:
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

Closed 2025-01-27.

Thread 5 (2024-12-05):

Suggestion: connect something to the two not connected FPC pins

alastairpatrick, 2024-12-05:
For example, the RP LED pins seem easy to route to the not connected FPC pins. A potential application is a user might jumper them to the FPGA LED pins and use them as an I2C bus, opening up a communication channel that was available on the original pico-ice.

vr2045, 2025-01-26:
Makes sense, added to the schematic.

vr2045, 2025-01-27:
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

Closed 2025-01-27.

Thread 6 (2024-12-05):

Power monitor cannot measure voltage of a battery connected to Vin...

alastairpatrick, 2024-12-05:
...because D5 prevents current from that source from flowing through the power monitor potential divider. A simple fix would be to connect the power monitor potential divider to Vin instead of Vbus. However, in some applications, this makes things worse, because the battery drains faster on account of the current through the potential divider. Idea 1: use a voltage follower, either BJT transistor or op-amp based, to reduce current through the potential divider. Idea 2: allow power monitoring to be turned on and off based on level of ADC6, so that no current flows when power monitoring is not in progress.

alastairpatrick, 2024-12-05:
Idea 3: or just remove the power monitor potential divider altogether. ADC7 is on a pin, so it would be easy for a user to connect a potential divider to it, with whatever approach to avoiding wasteful energy drain, externally.

alastairpatrick, 2024-12-05:
A related issue, so I'll put it here. When power is connected to Vbus (or Vin if the power monitor potential divider was moved to Vin), ADC7 will rise to half of the supply voltage. Some time later, delayed by soft start, the 3.3V regulator will bring RP IOVDD up to 3.3V. In the interim, ADC7 is more than 0.5V above IOVDD. ADC7 is not a fault tolerant IO, so it's outside briefly absolute maximum rating. It could be fixed with a clamping diode across R29.

alastairpatrick, 2024-12-05:
I like this as a compromise. By default, there is no wasteful battery drain. User can use the power monitor by adding one external resistor. They can tailor the resistor value to the battery voltage.
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

alastairpatrick, 2024-12-05:
Adding R29 makes it possible to connect directly to the positive terminal of a nominally 3.6V lithium battery. R29 is 2.2K so that at fully charged battery at about 4V yields 3.3V on GPIO47_ADC7. An external resistor in series with R29 allows for higher battery voltages. R29 acts as a current limiting resistor if ADC7 is misused, e.g. connected directly to the positive terminal of a 12V battery
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
.

vr2045, 2025-01-27:
This makes sense.
Implemented on the board. Thank you for the feedback!

Closed 2025-01-27.

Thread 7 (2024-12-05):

Switch bottom contact FPC with top contact FPC...

alastairpatrick, 2024-12-05:
... to be consistent with the Adafruit RP2350 Feather board. This could help reduce user error, such as connecting the pico2-ice to a board in a way that causes reverse polarity or a short. This would require some routing changes. In order to preserve the currently good routing of the HSTX differential pairs, I suggest leveraging the flexibility of HSTX bit crossbar to reverse the pin assignments of the HSTX pins. The assignments of the two GPIOs, SCL and SDA need not, I think, be assigned to different RP pins, but would have to be routed differently. This would require some changes to software written for the Adafruit RP2350 Feather board to make it work on pico2-ice, but it should be minor.

timoksn, 2024-12-05:
two possible options
-----
-----
**Slide Lock (~0.7USD) -  Mfr.#: F32Q-1A7H1-11022**
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
https://www.mouser.com/ProductDetail/Amphenol-Aorora/F32Q-1A7H1-11022?qs=xZ%2FP%252Ba9zWqbp%2FwxqDihMFA%3D%3D

-----
**Flip Lock (~$1.7USD) -  Mfr. #:FH12A-22S-0.5SH(55)**
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
https://www.mouser.com/ProductDetail/Hirose-Connector/FH12A-22S-0.5SH55?qs=wXhBCuSapIMPTS3Fn6eKNQ%3D%3D

vr2045, 2025-01-26:
I do like the flip lock. Will use that for the next version of the board.

I like the ability to keep the FW the same as what the Adafruit has. Would prefer to not make changes as a result.

Regardless, we should document the right way to insert the flex clearly. Especially if its different than the Adafruit. Worst case, if theres a short, this should not damage anything. We need to analyze this a bit.

vr2045, 2025-01-26:
If the flex is flipped, +3V3 gets shorted to ground. The PTC fuse will limit current and dissipation through this board.
Its not clear what happens at the other end though.

vr2045, 2025-01-27:
Resolved by using the same connector as on the RPi reference design: SFV22R-2STE1HLF

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

Closed 2025-01-27.

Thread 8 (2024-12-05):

ADC7 routing suggestion

alastairpatrick, 2024-12-05:
I found routing ADC7 to its potential divider like this helped reduce routing congestion in a busy part of the board.
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

alastairpatrick, 2024-12-05:
Looking at the latest PCB, this has been done already. Closing.

Closed 2024-12-05.

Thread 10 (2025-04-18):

suggestion: Add revision in PCB silkscreen

timoksn, 2025-04-18:
Add revision in PCB silkscreen.

vr2045, 2025-04-18:
Good idea!

timoksn, 2025-04-18:
ahh. sorry about that. I need to open my eyes

Closed 2025-04-18.

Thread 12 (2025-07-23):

Revisions to the Kicad Files

frohro, 2025-07-23:
Hi All,

I am teaching Digital Design this fall quarter, and am planning to make an order of pico2-ice units to JLCPCB.   To get ready for this, in the design files, I have added:

- A bunch of datasheets that were missing  (I did not include resistor or capacitor datasheets.)
- LCSC Part numbers
- 3D Models (I'm working on this now.)

I saw the note about the SWD connector maybe causing shipping issues.  For me, this isn't really a problem as I am ordering ten shipped here to be used here, not reshipped.  Are there other issues I should address?   Would you like me to do a pull request (after the class is over to make sure bugs have been discovered?)   I have tested the pico-ice to make sure I am happy with it, but I am planning to move on to the pico2-ice (which I have not played with), because it is the one that is receiving the love now, and is better, and the price to order from JLCPCB is about the same as if I made an order for the pico-ice.  Are there any other bugs you are aware of that I should think about addressing?  I would also be happy to share my changes with you earlier, especially if you wish to make some changes too, or would like to add some boards to my order of ten, for yourselves.

Thanks for all your good work on the pico-ice series!

Rob

frohro, 2025-07-24:
Did you have any problems with the fact your layout is different than what was recommended in the [RP2350 datasheet page 452](https://datasheets.raspberrypi.com/rp2350/rp2350-datasheet.pdf)?  I substituted a [different inductor](https://jlcpcb.com/partdetail/AbraconLLC-AOTA_B201610S3R3_101T/C42411119), because I could not find the one you specified.

josuah, 2025-08-11:
I think most of the activity happens on the chat server, you will have better luck of getting an answer there.

> There was also a problem with long start time for the crystal, which might have been because the layout is a bit different to the recommendation?

> Yes, that's been fixed on the purple version...
> We followed the reference design AFAIK...

https://discord.gg/JyHuNKHXbC

vr2045, 2025-08-11:
No changes planned as of now. Users haven't reported any significant issues so that far.
Good luck with the course!

frohro, 2025-08-12:
Thank @vr2045 and congratulations on that!  Even just adding JLCPCB part numbers, 3D models, etc. makes me a little nervous to order as many as I need.  :-)  I plan on it though.
Thanks again!
Rob

vr2045, 2025-08-12:
Good luck on this! Do share your experience with the course and we can propagate it to other profs who are using this board in their courses as well.

Do watch for the oscillator load cap change to 10pF. I think you saw this already on the Discord...

Please feel free to make a PR to the repo with your changes so we can include this in the design for other users as well!
If you do decide to submit a PR for this, please dont include any schematic or layout changes that affect the gerber itself.

Closed 2025-08-12.

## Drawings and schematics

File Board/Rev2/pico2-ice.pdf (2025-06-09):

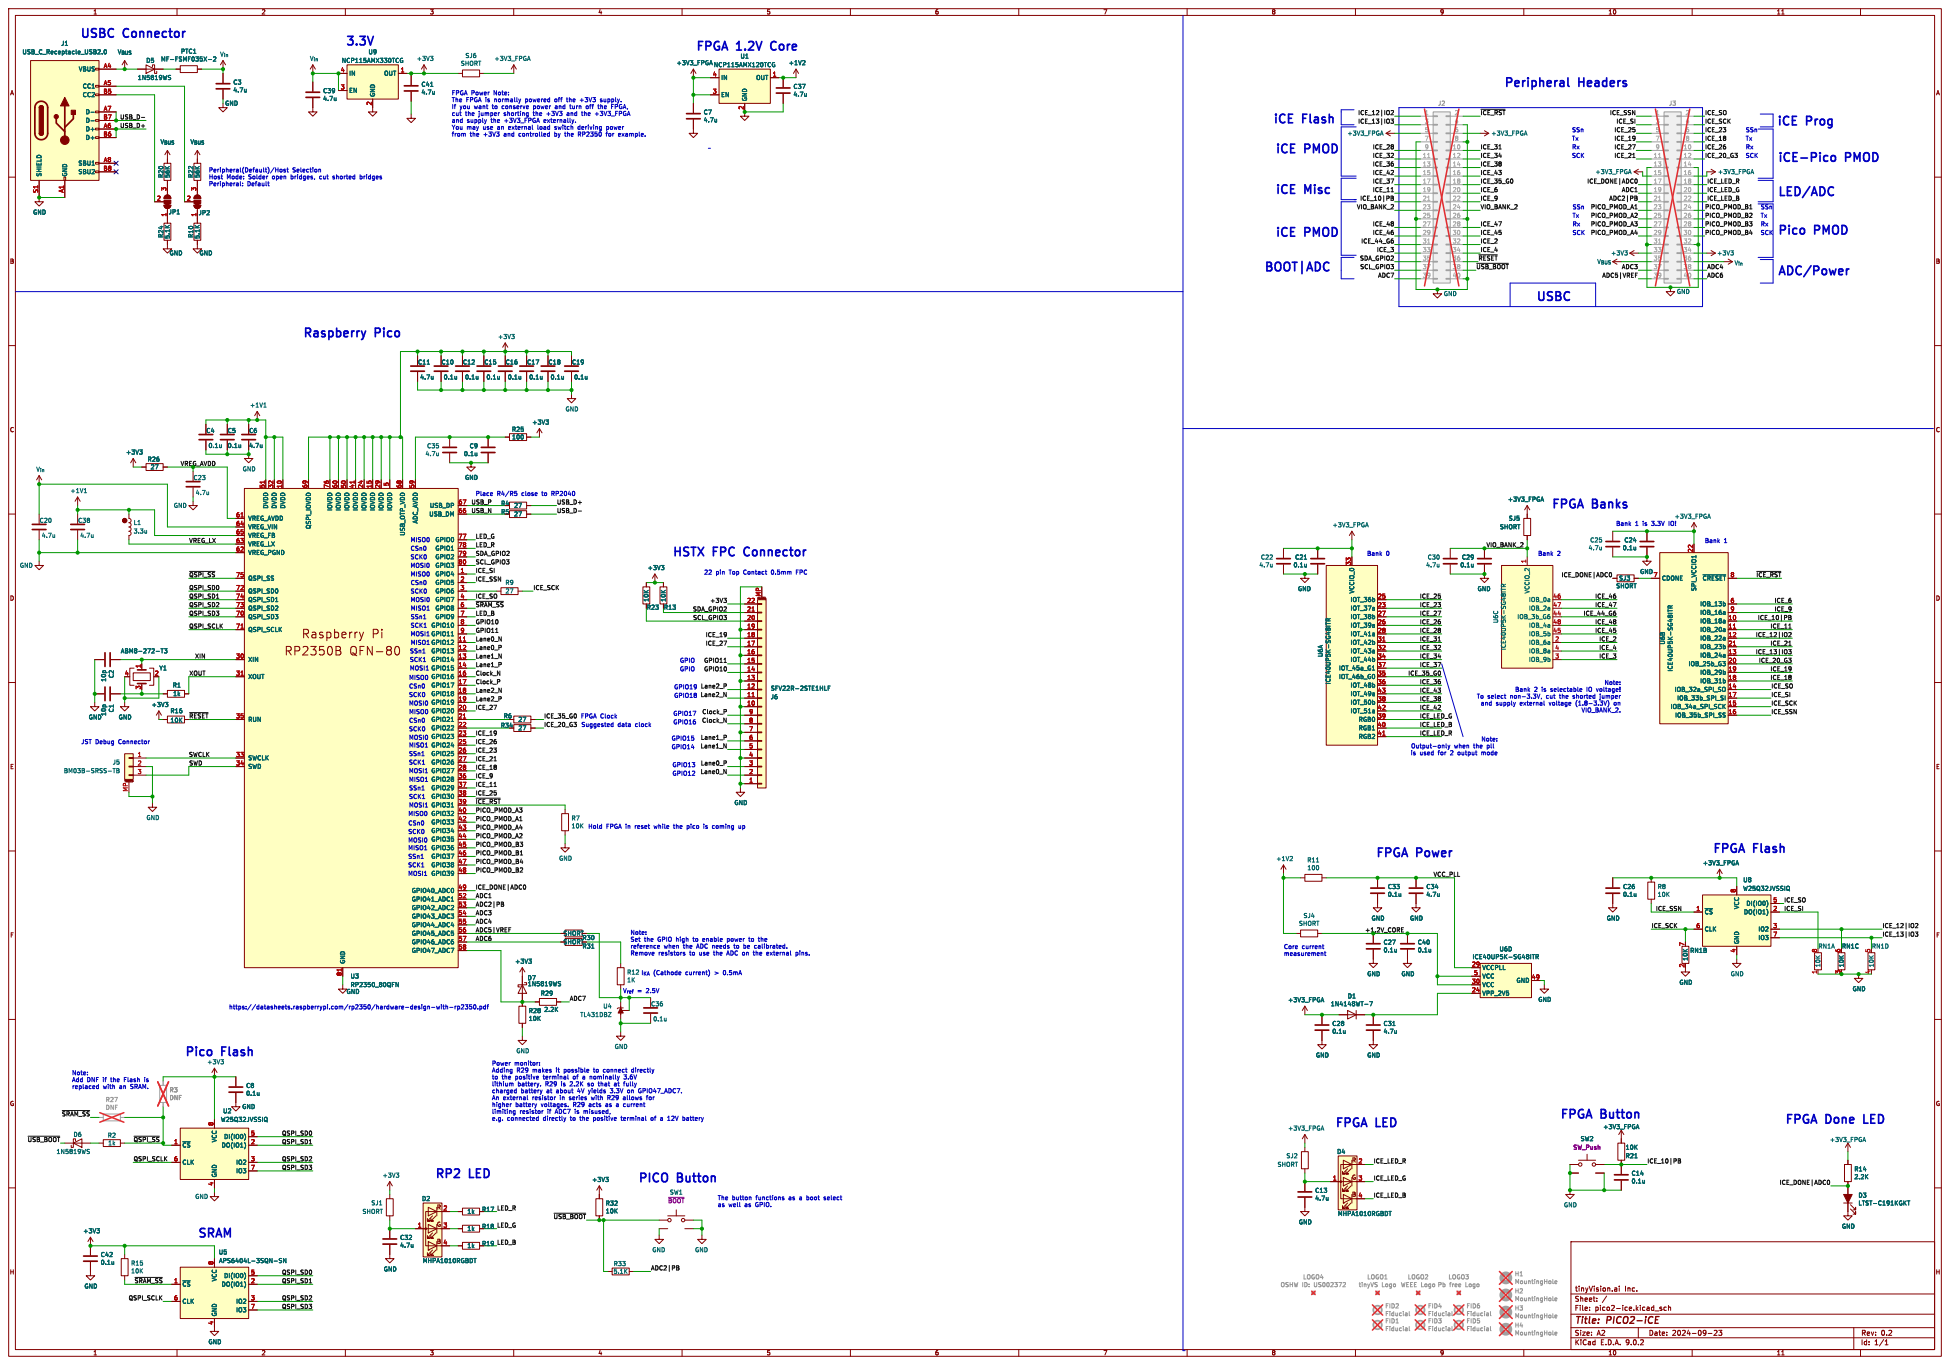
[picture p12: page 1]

is used for 2 output mode

https://datasheets.raspberrypi.com/rp2350/hardware-design-with-rp2350.pdf

Note: Add DNF if the Flash is

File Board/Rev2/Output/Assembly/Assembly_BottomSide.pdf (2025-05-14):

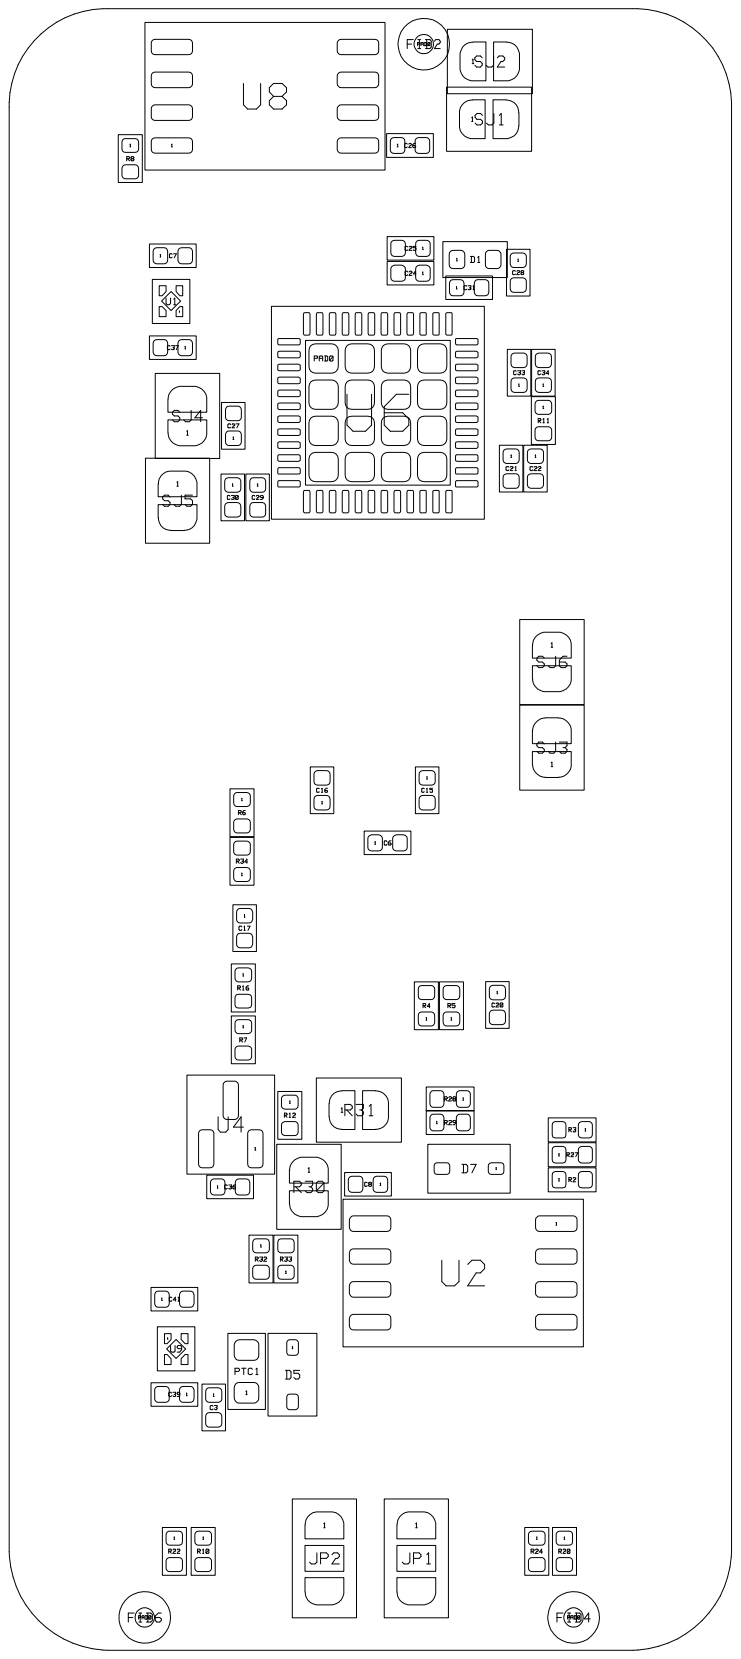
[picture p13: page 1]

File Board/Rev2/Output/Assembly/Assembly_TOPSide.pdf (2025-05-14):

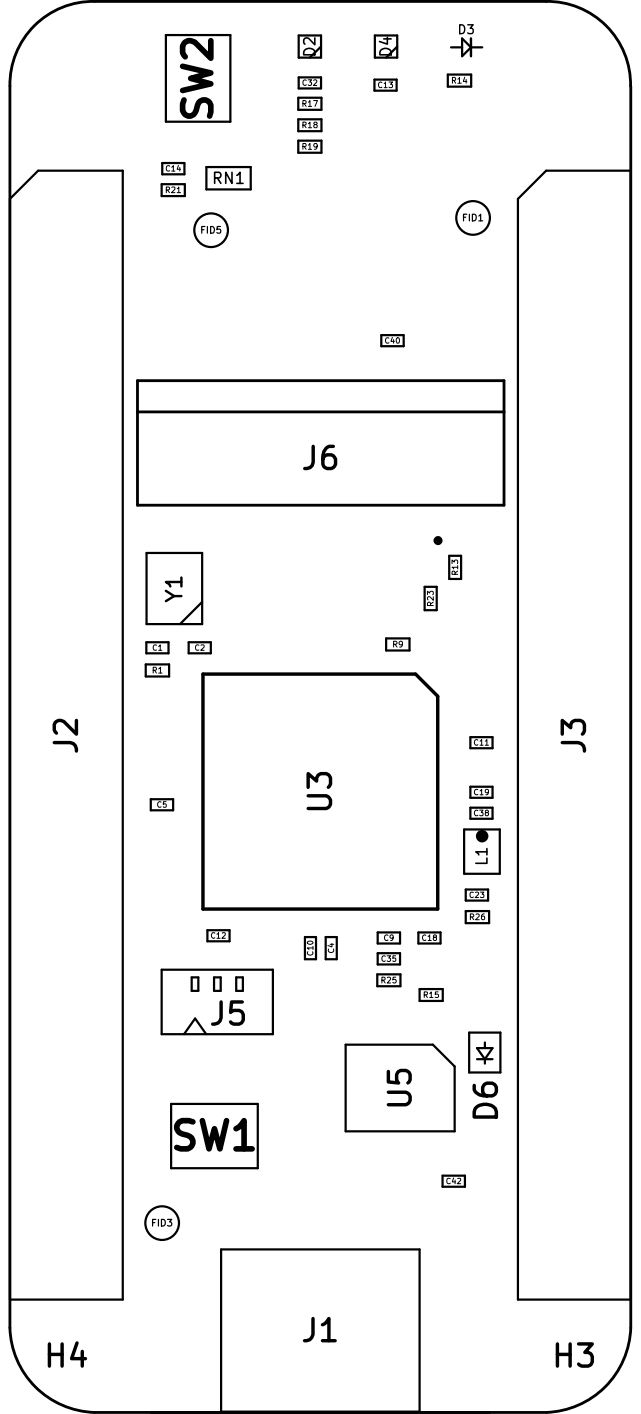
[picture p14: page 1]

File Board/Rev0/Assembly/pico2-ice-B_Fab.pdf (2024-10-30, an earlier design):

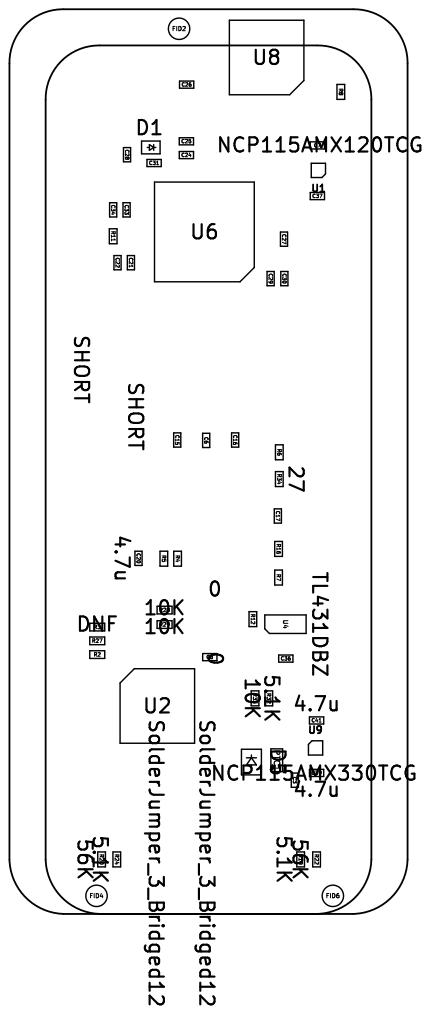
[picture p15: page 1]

Id: 1/1 Title: pico-ice

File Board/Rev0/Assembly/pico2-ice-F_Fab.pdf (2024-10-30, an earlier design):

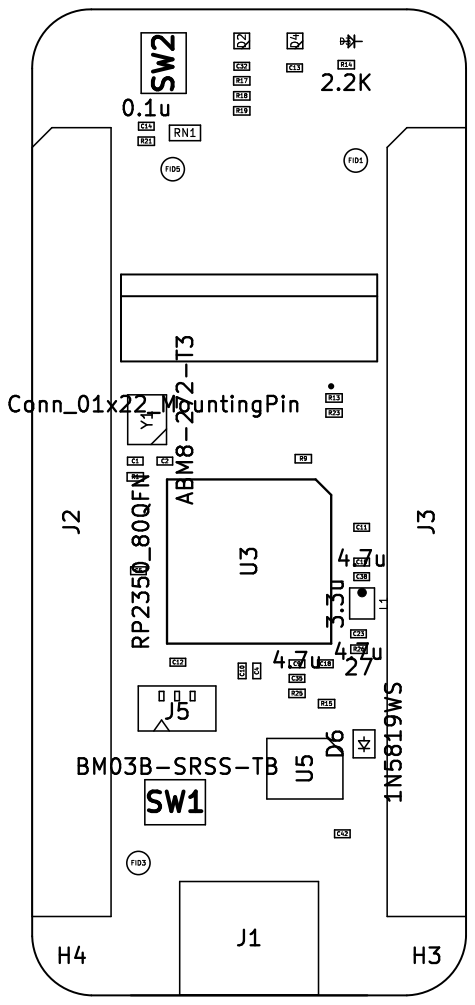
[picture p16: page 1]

Id: 1/1 Title: pico-ice

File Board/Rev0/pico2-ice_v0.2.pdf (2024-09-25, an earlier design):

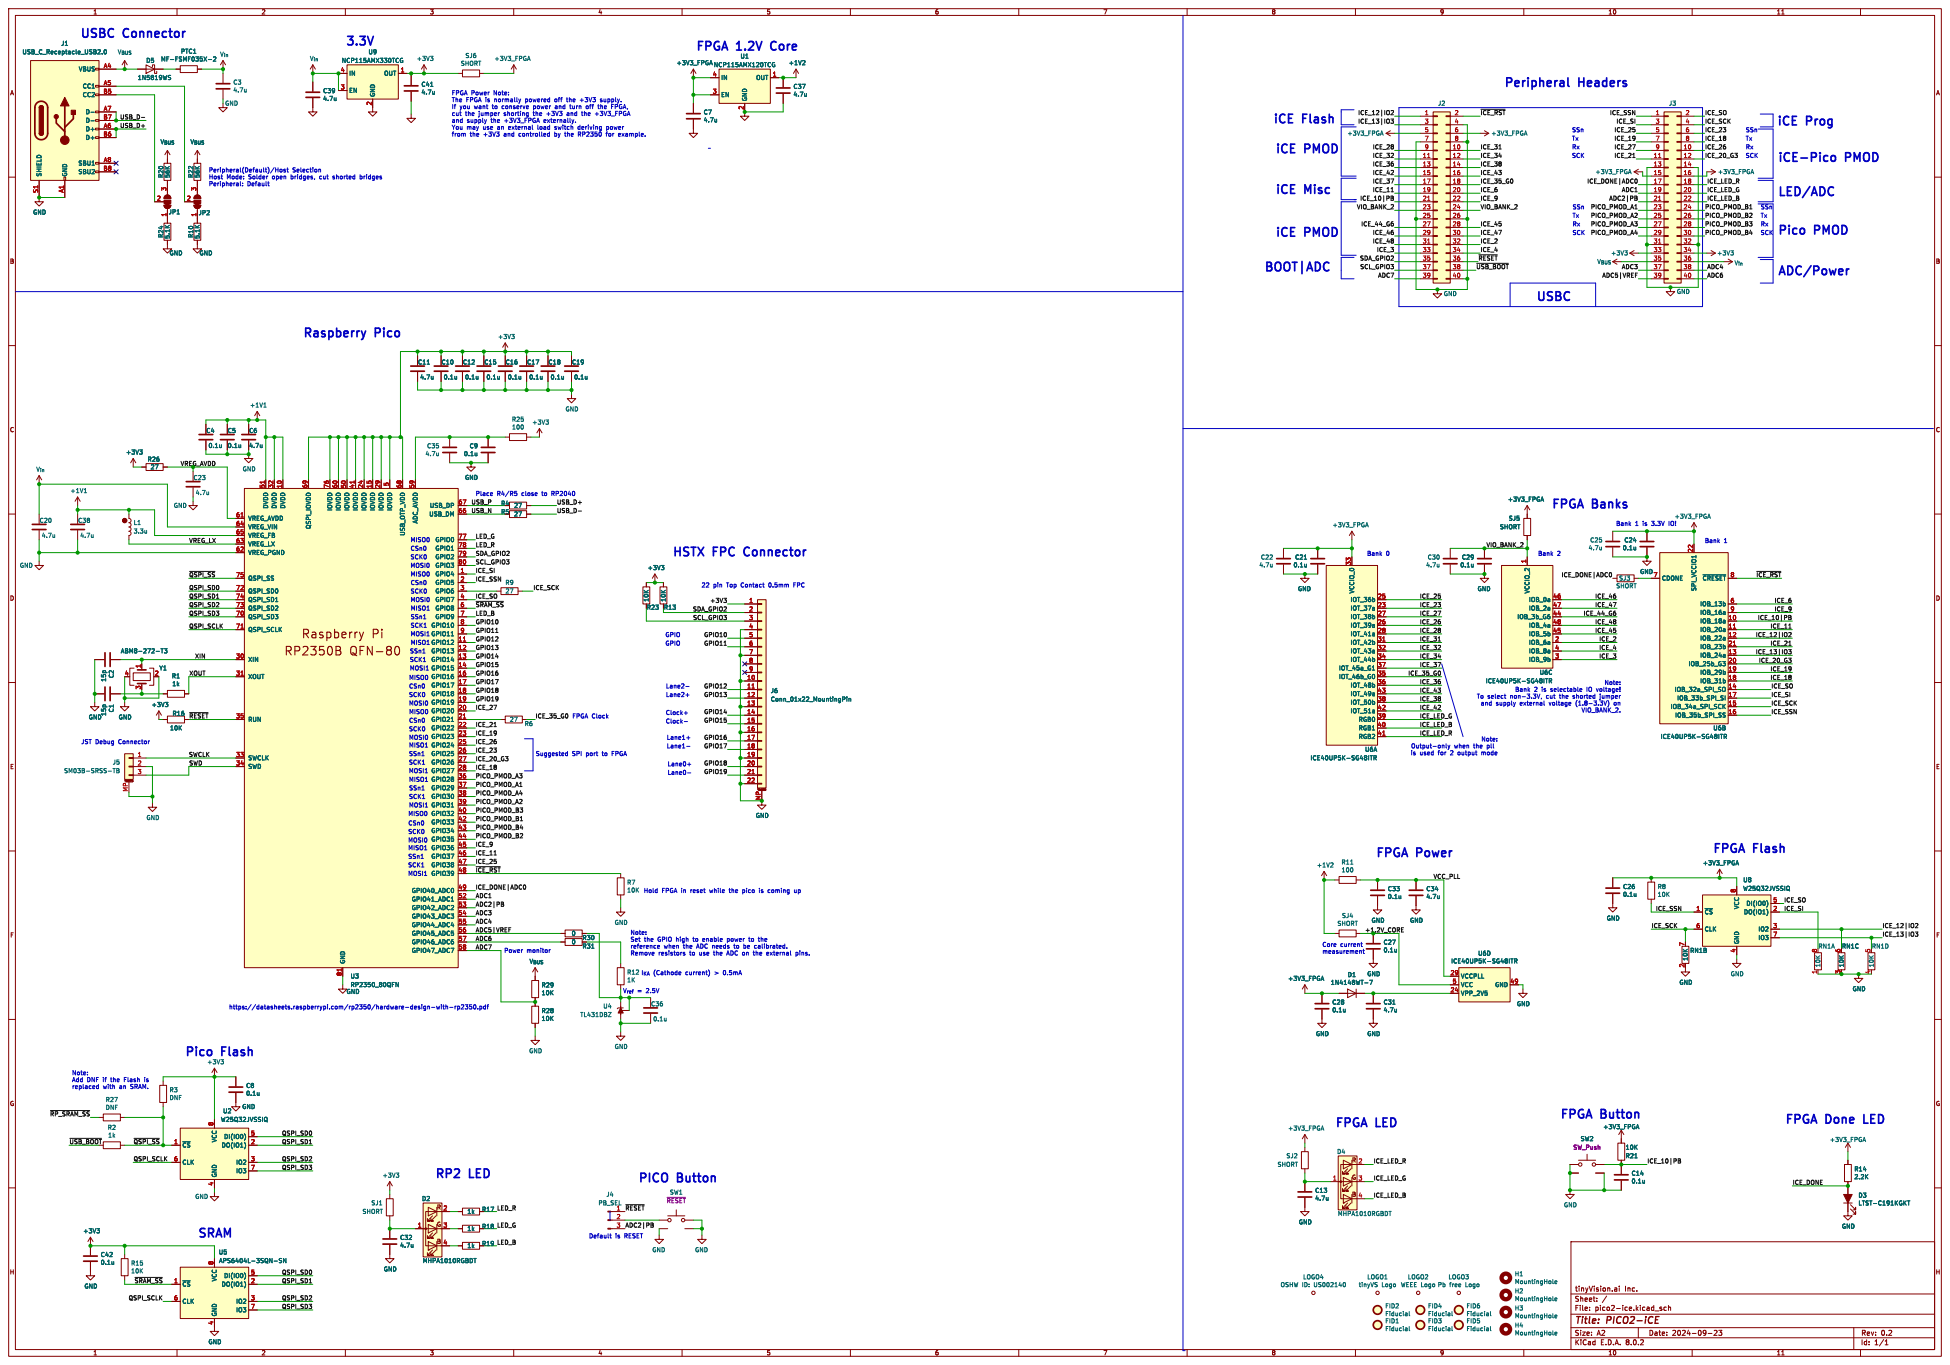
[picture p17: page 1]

22 pin Top Contact 0.5mm FPC

CSn0 Note: Add DNF if the Flash is

Lane2- Lane2+ Hold FPGA in reset while the pico is coming up Note: Set the GPIO high to enable power to the
Lane1- Clock- Clock+
Lane0- Lane1+

ICE_35_G0
FPGA Clock Suggested SPI port to FPGA

is used for 2 output mode FPGA Power
100 +1V2 +3V3_FPGA
0.1u GND GND

Core current measurement SRAM

https://datasheets.raspberrypi.com/rp2350/hardware-design-with-rp2350.pdf

FID6 Fiducial LOGO3 Pb free Logo

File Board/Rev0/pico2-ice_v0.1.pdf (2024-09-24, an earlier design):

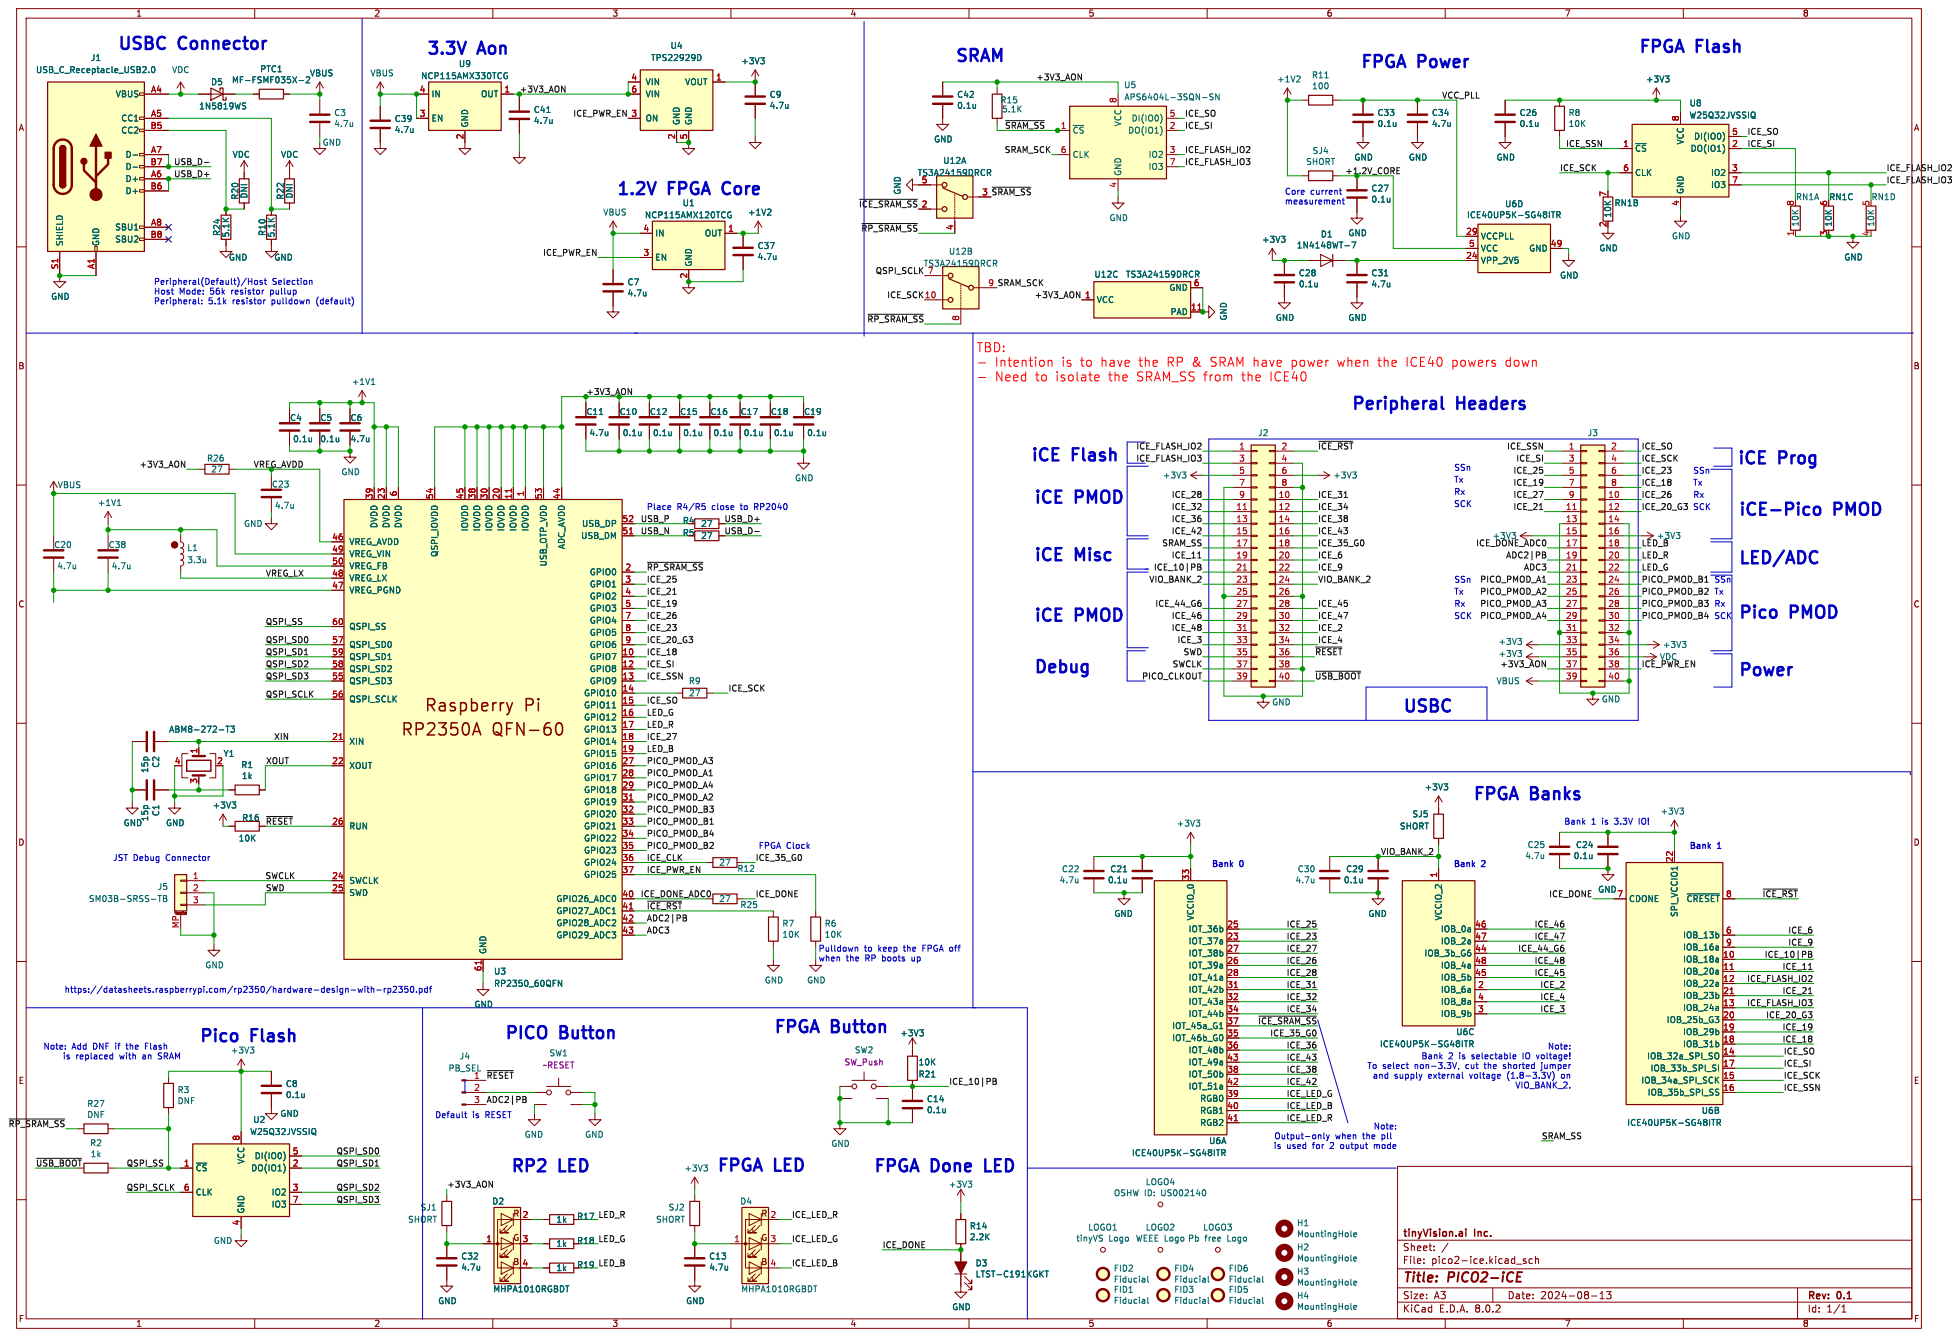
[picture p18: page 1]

- Need to isolate the SRAM_SS from the ICE40

TxSSn Rx SSn SCK Rx Tx SSn TxRx USBC

1 GPIO7 10 IOVDD 11 GPIO8 12 GPIO9 13 GPIO10 14 GPIO11 15 GPIO12 16 GPIO13 17 GPIO14 18 GPIO15 19 GPIO0 2 IOVDD 20 XIN 21 XOUT 22 DVDD 23 SWCLK 24 SWD 25 RUN 26 GPIO16 27 GPIO17 28 GPIO18 29 GPIO1 3 IOVDD 30 GPIO19 31 GPIO20 32 GPIO21 33 GPIO22 34 GPIO23 35 GPIO24 36 GPIO25 37 IOVDD 38 DVDD 39 GPIO2 4 GPIO26_ADC0 40 GPIO27_ADC1 41 GPIO28_ADC2 42 GPIO29_ADC3 43 ADC_AVDD 44 IOVDD 45 VREG_AVDD 46 VREG_PGND 47 VREG_LX 48 VREG_VIN 49 GPIO3 5 VREG_FB 50 USB_DM 51 USB_DP 52 USB_OTP_VDD 53 QSPI_IOVDD 54 QSPI_SD3 55 QSPI_SCLK 56 QSPI_SD0 57 QSPI_SD2 58 QSPI_SD1 59 DVDD

6 QSPI_SS 60 GND 61 GPIO4 7 GPIO5 8 GPIO6 9 GND GND GND R16

JST Debug Connector https://datasheets.raspberrypi.com/rp2350/hardware-design-with-rp2350.pdf

Pico Flash Note: Add DNF if the Flash

is used for 2 output mode

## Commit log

2024-08-13 Initial schematics
    [pico2-ice.kicad_pcb, pico2-ice.kicad_sch, pico2-ice.sch]
2024-09-24 Changed to 60 pin QFN version and made minor changes
    [pico2-ice.kicad_sch]
2024-09-24 Changed power to be simpler
    [pico2-ice.kicad_sch]
2024-09-24 Added ADC Vref and ADC's to connector
    [pico2-ice.kicad_sch]
2024-09-24 Added reference to ADC5, brought out various ADC's to the header and removed debug from the header
    [pico2-ice.kicad_sch]
2024-09-25 Simplified design, moved SSRAM to pico, cleaned up schematic
    [pico2-ice.kicad_sch]
2024-09-25 MOved a few pins so the FPGA could get a clock
    [pico2-ice.kicad_sch]
2024-10-14 Complete the routing for a review.
    [pico2-ice.kicad_pcb, pico2-ice.kicad_sch]
2024-10-14 Post merge
    [pico2-ice.kicad_sch]
2024-10-15 Update the design with feedbacks.
    [pico2-ice.kicad_pcb, pico2-ice.kicad_sch]
2024-10-15 Minor silkscreen edits
    [pico2-ice.kicad_pcb]
2024-10-17 Changed a few signals, changed button to boot select
    [pico2-ice.kicad_sch]
2024-10-18 Fixed floating nets
    [pico2-ice.kicad_sch]
2024-10-22 Sync the latest files.
    [pico2-ice.kicad_pcb, pico2-ice.kicad_sch]
2024-10-25 Complete the layout update for a review.
    [pico2-ice.kicad_pcb, pico2-ice.kicad_sch]
2024-10-27 Updated schematic PDF
2024-10-28 Updated layout with some grounds, fixed BoM
    [pico-ice.step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]
2024-10-30 Fixed fab drawing, corrected 3 color LED fab drawing
    [pico2-ice.kicad_pcb]
2024-11-25 Added JLCPCB files
    [pico2-ice_BoM.csv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]
2024-12-02 Fixed DONE error in schematic, issue #3
    [pico2-ice.kicad_pcb, pico2-ice.kicad_sch, pico2-ice.sch]
2024-12-15 initial pico default firmware
2025-01-26 Bugfixes for silkscreen PMOD, added DONE, unconnected RP22 pins, layout not yet complete
    [pico2-ice.kicad_pcb, pico2-ice.kicad_sch]
2025-01-27 PCB file updated
    [pico2-ice.kicad_pcb]
2025-01-27 Changed MPN on the FPC and updated datasheet link to the PSRAM
    [pico2-ice.kicad_sch]
2025-01-27 Added voltage monitor
    [pico2-ice.kicad_pcb, pico2-ice.kicad_sch]
2025-01-31 Unravelled the HSTX port after changing to a top contact part.
    [pico2-ice.kicad_pcb, pico2-ice.kicad_sch]
2025-02-03 pico2-ice gerber
    [pico2-ice-B_Cu.gbr, pico2-ice-B_Fab.gbr, pico2-ice-B_Mask.gbr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]
2025-04-16 add the pico-ice-sdk as submodule for doc generation
2025-04-16 Fix assembly link, update README.md, add some SDK text
2025-05-10 Added Rev 2 with an additional decoupling cap on the FPGA core power
    [pico2-ice.kicad_pcb, pico2-ice.kicad_sch, pico2-ice.sch]
2025-05-14 updated design and output files
    [pico2-ice-B_Cu.gbr, pico2-ice-B_Mask.gbr, pico2-ice-B_Paste.gbr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]
2025-05-16 output files
    [pico2-ice.csv, pico2-ice.kicad_pcb, pico2-ice.kicad_sch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]
2025-05-18 Added drill files
    [pico2-ice-NPTH.drl, pico2-ice-PTH.drl]
2025-06-09 Changed loading caps to 10pF, changed HSTX port naming to be consistent with other RPi boards with no routing changes, added docs for FPC connector
    [pico2-ice.kicad_pcb, pico2-ice.kicad_sch]
